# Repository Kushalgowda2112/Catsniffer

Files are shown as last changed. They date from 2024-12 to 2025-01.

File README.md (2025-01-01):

# **CatSniffer**

## Overview

CatSniffer 😼 is a multiprotocol, multiband device designed for sniffing, communicating, and attacking IoT (Internet of Things) devices. Shaped as a highly portable USB stick, it integrates powerful chips like **TI CC1352**, **Semtech SX1262**, and either the **RP2040** (for V3 and newer) or **Microchip SAMD21E17** (for V2 and earlier).

This device serves as a comprehensive tool for IoT security researchers, developers, and enthusiasts. CatSniffer is compatible with a wide range of software, including:

- SmartRF Packet Sniffer
- Sniffle
- zigbee2mqtt
- Z-Stack-firmware
- Ubiqua Protocol Analyzer
- Custom applications tailored to your specific needs

---

## Supported Technologies

CatSniffer can operate across multiple protocols:
- **LoRa**
- **Sub-1 GHz**
- **2.4 GHz**

Inspired by the work of Michael Ossmann and tools like the YardStick, GreatFET, HackRF, and Ubertooth, CatSniffer pays homage to the open-source hardware community.

---

## Versions

CatSniffer has evolved through several iterations, each improving on the previous:
- **CatSniffer v1.2**
- **CatSniffer v1.3**
- **CatSniffer v2.0**
- **CatSniffer v2.1**
- **CatSniffer v3.1**

All versions are supported, but newer versions include additional features and enhancements. Firmware for each version is tracked separately within the repository for clarity and ease of access.

---

## Protocols Supported

CatSniffer is compatible with the following protocols:
- **Thread**
- **Zigbee**
- **Bluetooth 5 Low Energy (BLE)**
- **IEEE 802.15.4g**
- **6LoWPAN**
- **LoRa/LoRaWAN**
- **Wi-SUN**
- **Amazon Sidewalk**
- **mioty®**

---

## Features

- **Multiprotocol and Multi-Band:** Operates across LoRa, Sub-1 GHz, and 2.4 GHz frequencies.
- **Auto Programming:** Integrated bootloader from TI CC; no external programmer needed.
- **User-Friendly Design:** Includes LEDs for status, reset buttons, and a general-purpose button.
- **Customizable:** SMA port for antenna selection and support for custom firmware or software development.
- **Cross-Platform Compatibility:** Works with Windows and Linux.

---

## Compatible Software

CatSniffer works with multiple software tools for sniffing and debugging:
- **Smart RF Packet Sniffer 2**
- **Wireshark**
- **Sniffle**
- **zigbee2mqtt**
- **Z-Stack-firmware**
- **pycatsniffer** (Beta)
- **Ubiqua Protocol Analyzer**

---

## Pre-requisites for Building Firmware

- **IDE:** Arduino IDE for RP2040 or SAMD21E17
- **Compiler:** Code Composer Studio (tested with CCS 10.2)
- **SDK:** SimpleLink CC13x2 and CC26x2 SDK
- **Programming Language:** Python 3

---

## License

- **Firmware License:** Released under a **GNU AGPL v3.0** license. See the `LICENSE` file for more information.
- **Hardware License:** Released under a **CERN Open Hardware Licence v1.2**. See the `LICENSE_HARDWARE` file for more details.

---

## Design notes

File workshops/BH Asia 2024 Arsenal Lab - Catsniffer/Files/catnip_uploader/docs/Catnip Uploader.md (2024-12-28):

This script works to upload firmware from the releases page to the CatSniffer Board V3.x. 
>[!IMPORTANT]
>The current version of the **Catnip** requires the lasted version of the [**SerialPassthroughwithboot**](https://github.com/ElectronicCats/CatSniffer-Firmware/releases/download/board-v3.x-v1.1.0/SerialPassthroughwithboot_RP2040_v1.1.uf2)
## Getting Starter
The struct files from the repo is:
``` bash
.catnip-uploader:
├── catnip_uploader.py
├── cc2538.py
├── releases.json
└── requirements.txt
```

To initialize first we need to install de dependencies packets from the *requirements.txt*. 

>[!NOTE]
>We recommend use virtual environment to avoid dependencies errors.

To install de requirements run the next command:  `pip install -r requirements.txt`
Requirements packets:
- `typer==0.9.0`
- `pyserial==3.5`
- `requests==2.31.0`
- `intelhex==2.3.0`
- `python-magic==0.4.27`

>[!IMPORTANT]
>To install **python-magic** may have additional dependencies depending on your OS, [read more](https://github.com/ahupp/python-magic#dependencies): 

### Available commands
Commands

#### Releases
Release commands
Show the current releases loaded from the board version 3
##### Usage
To show the current releases run the next command:
```bash
$> python3 catnip_uploader.py releases
Releases available:
0: airtag_scanner_CC1352P_7.hex
1: airtag_spoofer_CC1352P_7.hex
2: sniffer_fw_CC1352P_7.hex
3: sniffle_CC1352P_7.hex
```
#### Load
load_commands Load commands
Load  the selected firmware to the board, this command have two options.
- **Firmware**: This options is a integer value from the index of the available firmware releases
- **Comport**: The Path to the board serial com
##### Usage
>[!NOTE]
>First you need to know the index of the firmware you want to upload, exec the **releases** command if you don't know what index you need.

```bash
$> python3 catnip_uploader.py load 0 /dev/cu.usbmodem101
Uploading airtag_scanner_CC1352P_7.hex to /dev/cu.usbmodem1101
Downloading airtag_scanner_CC1352P_7.hex
Uploading airtag_scanner_CC1352P_7.hex to /dev/cu.usbmodem1101
Opening port /dev/cu.usbmodem1101, baud 500000
Reading data from firmware.hex
Firmware file: Intel Hex
Connecting to target...
CC1350 PG2.0 (7x7mm): 704KB Flash, 20KB SRAM, CCFG.BL_CONFIG at 0x000AFFD8
Primary IEEE Address: 00:12:4B:00:2A:79:C0:96
    Performing mass erase
Erasing all main bank flash sectors
    Erase done
Writing 720896 bytes starting at address 0x00000000
Write 208 bytes at 0x000AFF300
    Write done                                
Verifying by comparing CRC32 calculations.
    Verified (match: 0x99d1c8f1)
Done uploading airtag_scanner_CC1352P_7.hex to /dev/cu.usbmodem1101 
```

After finished you can use the CatSniffer with the selected firmware.

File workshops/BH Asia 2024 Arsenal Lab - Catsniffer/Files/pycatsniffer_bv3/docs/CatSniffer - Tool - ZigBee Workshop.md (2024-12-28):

This document show how to get key from a ZigBee communication and decrypt to know the value, for the POC was used a *Mi Smart Sensor Set* of Xiaomi.

# Setting up
Firs we need to clone the [CatSniffer tools set](https://github.com/ElectronicCats/CatSniffer-Tools), this repo contains the follow tools:
```bash
.catsniffer-tools
├── catnip_uploader
├── cc2538-bsl
└── pycatsniffer_bv3
```

Create a virtual environment to install the requirements, for more information about the **cc2538-bsl** read the [documentation repo](https://github.com/ElectronicCats/CatSniffer-Tools/tree/main/cc2538-bsl).

## Catnip Uploader

>[!IMPORTANT]
> To load the firmware in this way you need the lasted version of the **SerialPassthroughwithboot**.

With this tools we can upload the lasted firmware to the board v 3.x, to run first install the *requirements.txt*, with the following command: `pip install -r requirements.txt`.
Once the requirements are successfully installed we can upload the firmware:
- Run the *releases* command to know what releases are available:
	- `python3 catnip_uploader.py releases`
- Find the index of the *sniffer_fw_CC1352P_7.hex* and run the next command with the path of the port assigned to the board:
	- `python3 catnip_uploader.py load 0 <PORTCOM>`

For more information about the **Catnip Uploader** read the [repo](https://github.com/ElectronicCats/CatSniffer-Tools/blob/main/catnip_uploader/docs/Catnip%20Uploader.md).

> [!NOTE]
> if you have oldest version or you are not sure about what version of the **SerialPassthroughwithboot** you have, read the [**CC2538-bsl**](https://github.com/ElectronicCats/CatSniffer-Tools/tree/main/cc2538-bsl) to know how to upload the firmware with oldest version.
## PyCatsniffer
With the current virtual environment install the *requirements.txt* with the following command: `pip install -r requirements.txt`
Once the requirements are successfully installed we can continue installing the *dissectors*.
### Set the Dissector
We need to copy the three .lua files dissector to be able to read the information.
```bash
.dissectors:
├── catsniffer-blepi.lua
├── catsniffer-register.lua
└── catsniffer-rpi.lua
```

To copy the dissectors content we need to:
- Open Wireshark
- `Wireshark > About > Folders`
- Double click on the `Personal Lua Plugins` path (this create the folder path)
- Copy the content inside the *dissectors folder* into the **Personal Lua Plugins** folder
- Restart Wireshark

### Configure the DLT 147 value
To use wireshark and show the information we need to configure the USER DLT value to redirect the sniffer packet to the dissectors files.
- Open Wireshark
- `Preferences > Protocols > DLT_USER`
- Click on the `Edit...` button
- Create new entry
- The entry value are defined as:
	- DLT: User 0 (DLT=147)
	- Payload dissector: catsniffer_rpi
	- Header size: 0
- Click in *Ok* button
- Click in *Ok* button

if you have doubts with the installation read the [repo](https://github.com/ElectronicCats/CatSniffer-Tools/blob/main/catnip_uploader/docs/Catnip%20Uploader.md).

# Sniffing
To know how the *PyCatsniffer* works, please read the [repo](https://github.com/ElectronicCats/CatSniffer-Tools/blob/main/catnip_uploader/docs/Catnip%20Uploader.md).

We run the next command to sniff the IEEE 802.15.4 protocol, channel 11 and create a wireshark pipeline:
`python3 pycatsniffer.py /dev/cu.usbmodem101 -phy 1 -ch 11 -ff -ws -v`

Once the wireshark is open we can sniff the packets.
## Setting Up ZigBee Key
The **Default Trust Center Link Key** (Link Key) is a 16-bytes key.
The following key is defined by the ZigBee Alliance: `5A:69:67:42:65:65:41:6C:6C:69:61:6E:63:65:30:39`
To decrypt the packet information we need to add the key to the protocols section:
- `Wireshark > Preferences > Protocols > ZigBee`
- Edit the *preconfigure keys*
- Add new entry
- Copy the Key value
- Add
- Close the protocols window

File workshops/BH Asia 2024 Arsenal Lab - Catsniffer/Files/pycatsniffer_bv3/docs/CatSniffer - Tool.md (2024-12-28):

# PyCatsniffer tool

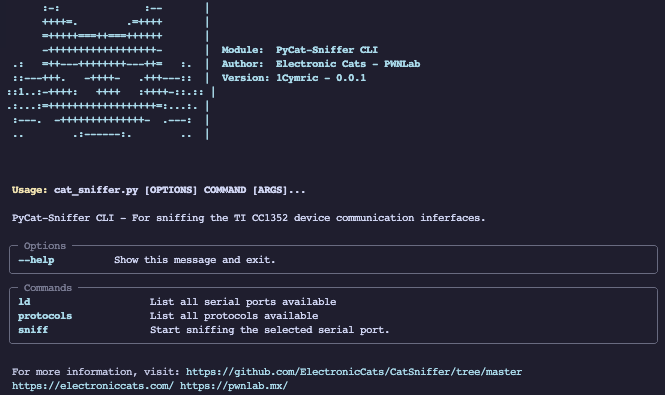
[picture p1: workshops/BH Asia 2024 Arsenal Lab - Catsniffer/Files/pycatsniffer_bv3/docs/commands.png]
commands

This tools is Command Line Interface (CLI) to communicate with the [**Sniffer_fw_CC1352P_7 firmware**](https://github.com/ElectronicCats/CatSniffer-Firmware/releases/) that you can upload with out catnip tool.

# Features
- This tool actually supports the next protocols:
	- Bluetooth Low Energy (BLE)
	- IEEE 802.15.4
	- ZigBee
- Multi platform support
- Direct wireshark communication with PIPE's
- Dump the received packets in:
	- Pcap Format
	- Hex Format

# Getting Starter
## Requirements
To install the requirements we need first [**Python 3**](https://www.python.org) installed and the environment variable to call python.
To initialize first we need to install de dependencies packets from the *requirements.txt*.

>[!NOTE]
>We recommend use virtual environment to avoid dependencies errors.

To install de requirements run the next command:  `pip install -r requirements.txt`
If all the requirements are satisfactory installed we can proceed to running the script.

## Setting up the Environment

### Wireshark
#### Set the Dissector
We need to copy the three .lua files dissector to be able to read the information.
```bash
.dissectors:
├── catsniffer-blepi.lua
├── catsniffer-register.lua
└── catsniffer-rpi.lua
```

To copy the dissectors content we need to:
- Open Wireshark
- `Wireshark > About > Folders`
- Double click on the `Personal Lua Plugins` path (this create the folder path)
- Copy the content inside the *dissectors folder* into the **Personal Lua Plugins** folder
- Restart Wireshark

#### Configure the DLT 147 value
To use wireshark and show the information we need to configure the USER DLT value to redirect the sniffer packet to the dissectors files.
- Open Wireshark
- `Preferences > Protocols > DLT_USER`
- Click on the `Edit...` button
- Create new entry
- The entry value are defined as:
	- DLT: User 0 (DLT=147)
	- Payload dissector: catsniffer_rpi
	- Header size: 0
- Click in *Ok* button
- Click in *Ok* button
## Available Commands
### List Devices - ld

```bash
$ python cat_sniffer.py ld
```

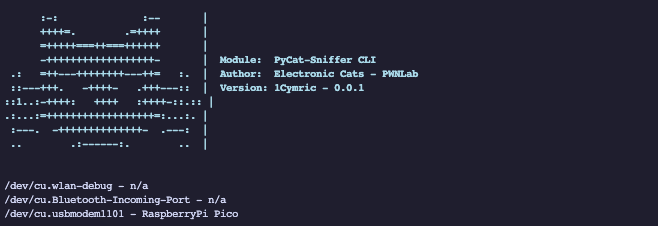
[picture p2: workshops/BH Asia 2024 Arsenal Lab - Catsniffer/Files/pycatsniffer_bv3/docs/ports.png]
List devices

This commands show the available com ports, running this command we can view what port is available and if our CatSniffer is connected.

### Protocols - protocols
```bash
$ python cat_sniffer.py protocols
```
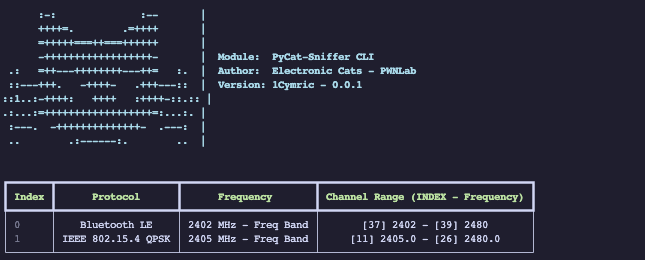
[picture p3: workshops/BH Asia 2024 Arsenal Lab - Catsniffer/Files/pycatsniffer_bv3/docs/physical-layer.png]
physical Layer protocols

This command show the available protocols and description about the supported channels.

The command show a table with the information about the protocol support.
- **Index**: The index value to used when a [sniff](#) command is called.
- **Protocol**: Protocol name
- **Frequency**: The base frequency of the protocol
- **Channel Range**: Show the relation of the channel and the frequency, the index value is used in the *sniff* command to select the channel to sniff.

>[!NOTE]
>The Channel Range is showed in the min value and max value of the channel range available in the protocol.

### Sniffer - sniff

```bash
$ python cat_sniffer.py sniff --help
```

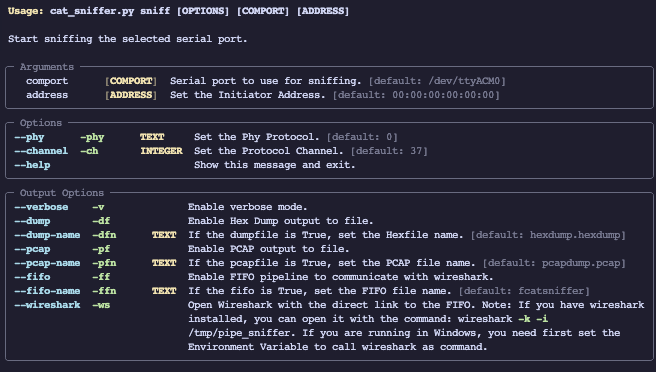
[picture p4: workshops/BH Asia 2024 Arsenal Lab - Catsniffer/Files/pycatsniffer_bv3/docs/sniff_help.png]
sniff Sniff Help


This commands initialize the sniff communication with the board, to start the sniffing the command requires some initial configuration.

#### Arguments:
- **comport**: This value is the path to the board serial com
- **address (experimental)**: This value is the MAC address of the device to follow the connection

#### Options
- **phy**: This value set the phy value, as refers in the [protocols section] correspond to the index value.
- **channel**: This is the value from the channel to sniff, this index values are showed in the protocols section.

When a different *phy* is selected, we need to specify the channel to sniffing.

#### Output Options
- **verbose**: Show the sniffed packets in the console.
- **dump**: Is a flag value, if we write this will generate a dump hex file
- **dump-name**: Is the flag value, if we write this with a value change the default dump name.
- **pcap**: Is a flag value, if we write this will generate a dump pcap file
- **pcap-name**: Is the flag value, if we write this with a value change the default dump name.
- **fifo**: This flags set a pipe line to communicate with wireshark
- **fifo-name**: Set the name of the pipe
- **wireshark**: This open a wireshark in the same thread of the script and open automatically the fifo. (Require the -ff option to open)

>[!IMPORTANT]
>If your are in windows to call Wireshark from the terminal you need to set the installation path to the Environmental Variables

### Examples calls

$SERIAL_PORT will be depending on your OS please check your serial port name by: 

```bash
$ python cat_sniffer.py ld
```
List devices

Default sniffing
- Protocol: BLE
- Channel: 37
- Verbose
```bash
$ python3 cat_sniffer.py sniff $SERIAL_PORT -v
```

Dump a pcap file with different BLE channel
- Protocol: BLE
- Channel: 39
- Dump File
```bash
$ python3 cat_sniffer.py sniff $SERIAL_PORT -ch 39 -df
```

Default sniffing
- Protocol: BLE
- Channel: 37
- Wireshark
```bash
$ python3 cat_sniffer.py sniff $SERIAL_PORT -phy 0 -ch 39 -ff -ws 
```

Dump a pcap file, hex file with custom name and IEEE 802.15.4 protocol
```bash
$ python3 cat_sniffer.py sniff $SERIAL_PORT -phy 1 -ch 11 -pf -df -dfn test.pcap
```

Dump a pcap file, hex file, verbose mode and show the packets on wireshark
```bash
$ python3 cat_sniffer.py sniff $SERIAL_PORT -df -pf -ff -ws
```

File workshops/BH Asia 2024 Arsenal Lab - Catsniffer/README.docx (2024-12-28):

# Practical IoT Hacking: Introduction to Multi-Band Hacking with the CatSniffer

Delve into the fascinating world of IoT (Internet of Things) with the CatSniffer - a powerful, multi-protocol, multi-band, and open-source board crafted for exploring, interacting, and potentially compromising IoT devices. This workshop offers an immersive, hands-on experience, teaching you how to create chaos among IoT devices and challenge real-world devices like property trackers.

Our engaging demonstrations are merely the tip of the iceberg of what you can achieve with the CatSniffer. The tool's exceptional flexibility allows the use of different tools for your security auditing needs, and our unique firmware broadens your learning horizon and amplifies the fun factor, irrespective of whether you're a novice or a seasoned expert in the field.

We invite you to join us on this journey of discovery, where we will harness the boundless capabilities of CatSniffer, fine-tuning your skills and transforming you into a maestro of IoT security auditing.

## Instructors

Paulino Calderon (@calderpwn) / https://calderonpale.com / https://pwnlab.mx / https://websec.mx / https://www.websec.ca

paulino@pwnlab.mx

Eduardo Contreras (@foreverwero) / https://electroniccats.com

e@electroniccats.com

## How to start

The first step is download our CatSniffer Tools repo, this contains all the tools to start the process.

Once you cloned the repo you can follow our Unleashing the Power of Catsniffer: Dive Deeper with Catnip (https://www.hackster.io/electronic-cats/unleashing-the-power-of-catsniffer-dive-deeper-with-catnip-82e1e4) tutorial posted in hackster.io to know how to use the Catnip tool to upload the firmware to the CatSniffer board.

## Additional References

- Link to this workshop: https://drive.google.com/drive/folders/1jL8F2wyyk_IrzVMoqUrraBWmWxnT-Cso
- Workshop booklet:

N/A

- Catsniffer on Github:

https://github.com/ElectronicCats/CatSniffer

- Catsniffer Wiki:

https://github.com/ElectronicCats/CatSniffer/wiki/

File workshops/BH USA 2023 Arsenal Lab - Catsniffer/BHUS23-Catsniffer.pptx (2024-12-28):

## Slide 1

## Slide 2

Practical IoT Hacking: Introduction to Multi-Band Hacking with the CatSniffer

Eduardo Wero (@foreverwero) / Paulino Calderon (@calderpwn)

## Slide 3

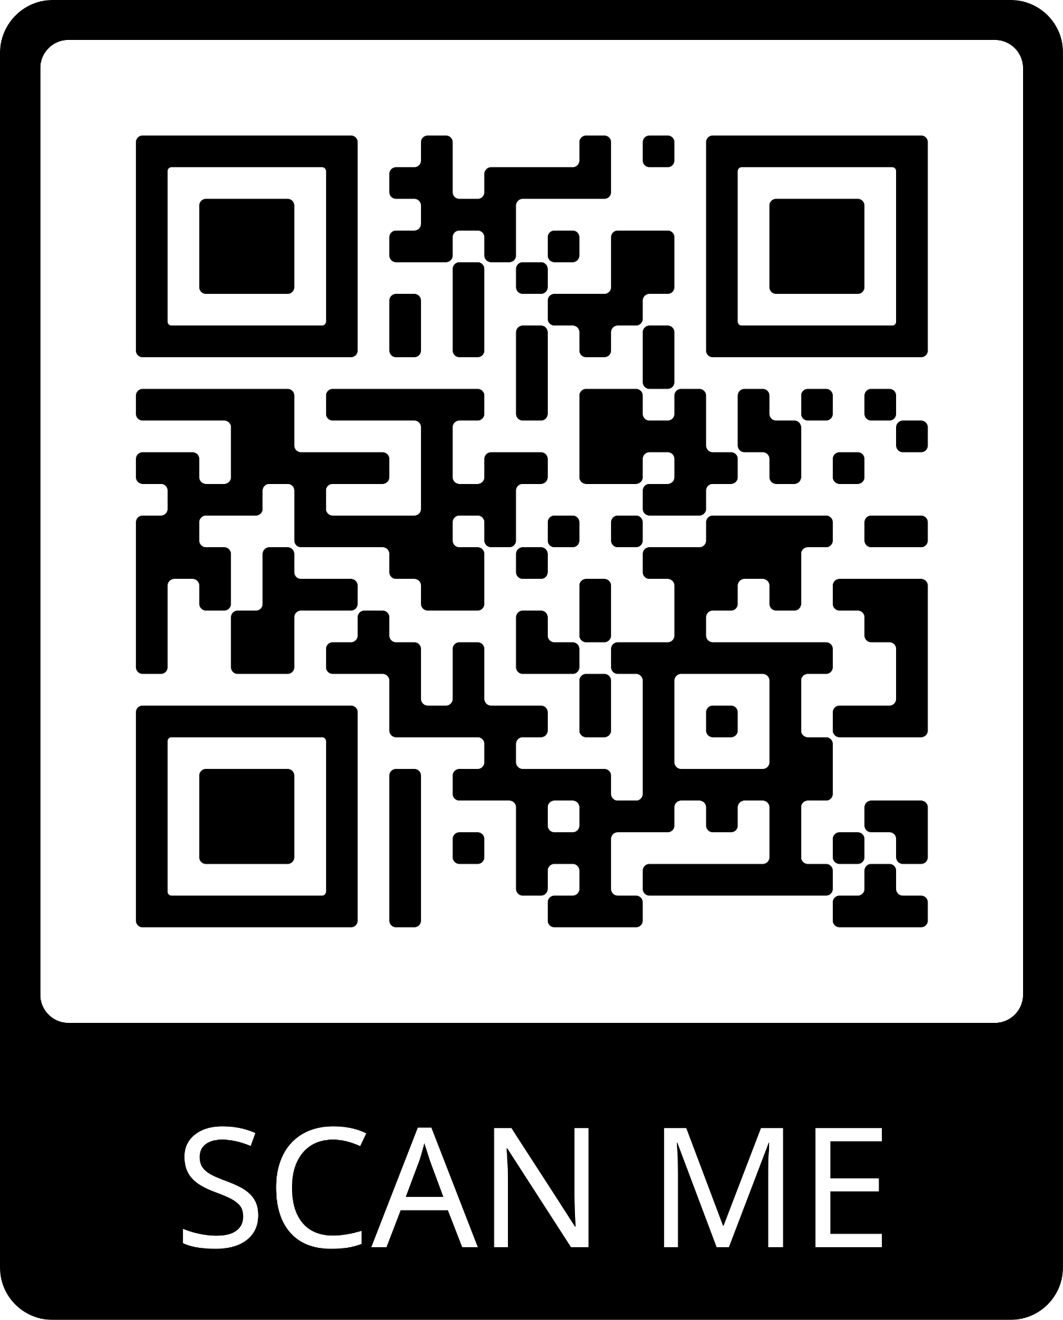
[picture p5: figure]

Workshop resources:

https://bit.ly/3Dsyqol

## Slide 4

CatSniffer

CatSniffer (😼) is an innovative, multi-protocol, multi-band open source circuit board made for sniffing, communicating, and attacking IoT (Internet of Things) devices. It was designed as a highly portable USB stick that integrates TI CC1352, Semtech SX1262, and Microchip SAMD21E17 (V1.x and V2.x)/RP2040 (V3.x).

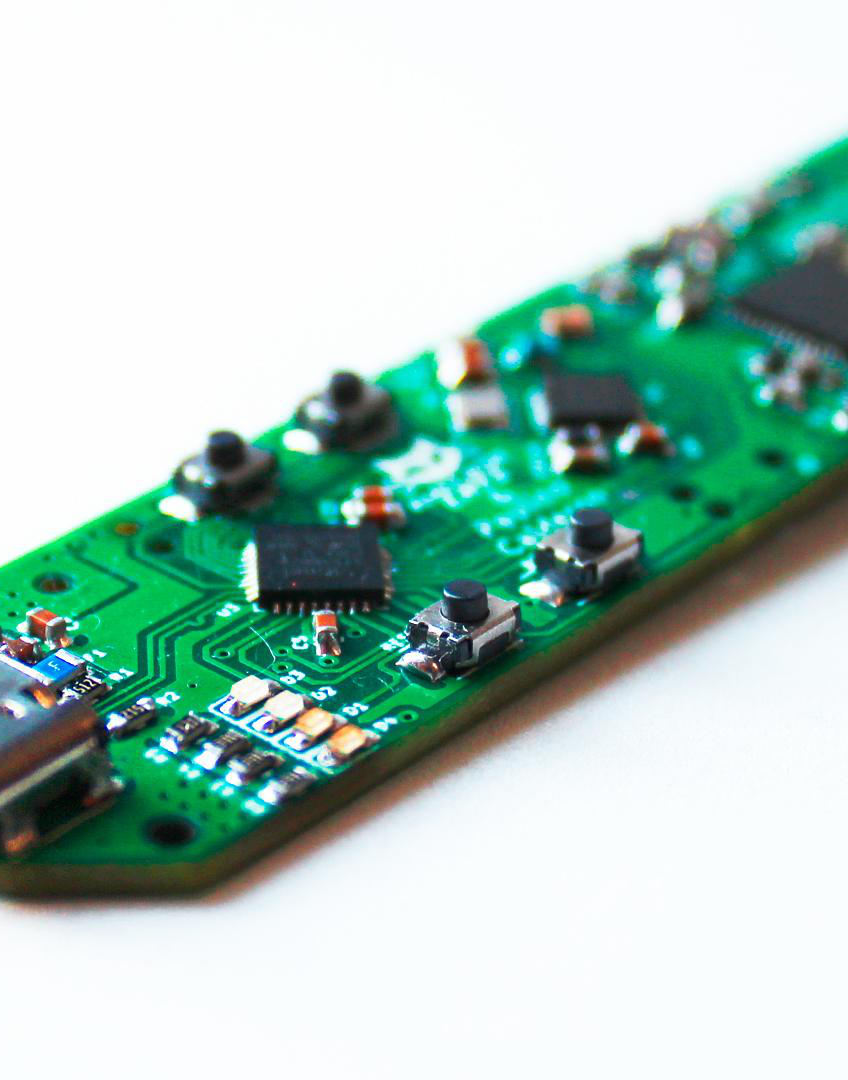
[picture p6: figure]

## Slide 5

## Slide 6

Supported software

This board is a Swiss army knife for IoT security researchers, developers, and enthusiasts. It's highly versatile, compatible with a wide array of software, including:
- Packet Sniffers (*)
- Security auditing tools
- Custom firmware developed by ElectronicCats/PWNLab
(*) It works in Windows with the latest Wireshark!

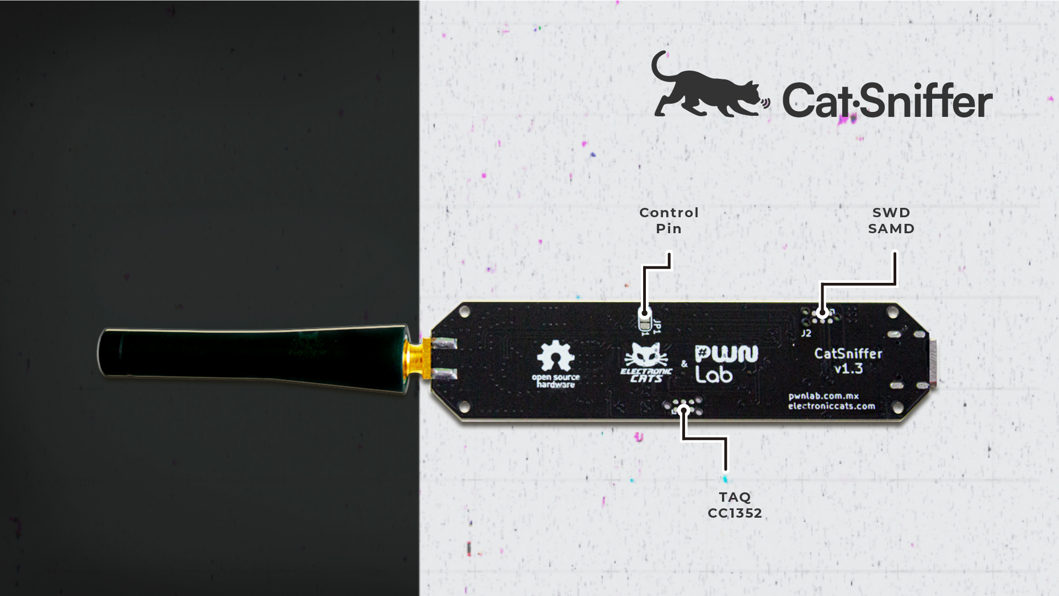
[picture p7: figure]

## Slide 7

Protocols

- Thread
- Zigbee
- Bluetooth 5 Low Energy (BLE)
- IEEE 802.15.4g
- 6LoWPAN (IPv6 over Low power Wireless Personal Area Networks)
- Sub 1Ghz and patented systems
- LoRa/LoRaWAN
Antenna support: 868/915 MHz up to 14 dBm, 2.4 GHz up to 20 dBm

1.x/2.x

- RP2040 microcontroller
- +Wi-SUN
- +Amazon Sidewalk
- +mioty®
Antena support: 433 MHz up to 13 dBm, 2.4 GHz up to 10 dBm

3.x

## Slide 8

SPI

Serial

SX1262

RF Switch

USB

RP2040

CC1352P7

JTAG

GPIOs

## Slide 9

Workshop prerequisites

To challenge yourself and follow along, you will need the following software (*):
- Workshop booklet
https://bit.ly/44yWQsj
- Code Composer Studio from https://www.ti.com/tool/CCSTUDIO
- Code sources from https://github.com/ElectronicCats/CatSniffer/
- Python3 (pyserial and other modules might be needed)
(*) It should be pre-installed in the Kali workstations but USBs with all the files should be available to copy the files to your machines!

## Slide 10

Flashing firmware from Linux

To program your Catsniffer with one of the firmwares available:
1. Locate the desired firmware. You will usually find official firmwares in .hex format.
https://github.com/ElectronicCats/CatSniffer/tree/master/firmware
1. Put the CatSniffer in upload mode for the CC1352P7, press reset for the RP2040 and the boot for the CC1352, then release the reset button and second the boot button, you shall see an animation on the LEDs in the CatSniffer, you are ready to upload the desire firmware to the CC1352.
2. Locate the utility cc2538-bsl.py found in the Code folder.
3. Install the requirements for cc2538-bsl.py by issuing the following commands:
$python3 -m pip install pyserial
$python3 -m pip install intelhex
1. Reset the RP2040 once you have flashed the CC1352P
2. If you would like to read serial information from a terminal, put back the CatSniffer in serial passthrough mode with the correct speed using Arduino IDE. (Optional)

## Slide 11

Practical examples

Follow along with booklet

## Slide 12

Hands on Lab #1: Sniffing BLE

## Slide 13

Learning objectives

1. Flash firmware for sniffing Bluetooth Low Energy connections
2. Basic usage of tools for analyzing BLE traffic
3. Packet structure of different types of BLE packets

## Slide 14

Hands on Lab #2: Detecting personal trackers

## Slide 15

Learning objectives

1. Learn about the technologies used in personal trackers
2. Learn how to detect personal trackers
3. Write custom firmware to detect personal trackers

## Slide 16

Hands on Lab #3: Spoofing personal trackers

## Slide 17

Learning objectives

1. Learn how to spoof personal trackers
2. Learn to craft custom BLE packets
3. Write firmware to communicate with devices over BLE

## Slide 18

Questions?

Eduardo Contreras (e@electroniccats.com)
Paulino Calderon (paulino@pwnlab.mx)
Catsniffer on Github
https://github.com/ElectronicCats/CatSniffer
Download this workshop: https://bit.ly/3Dsyqol

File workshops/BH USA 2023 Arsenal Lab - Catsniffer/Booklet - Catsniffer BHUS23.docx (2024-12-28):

# Practical IoT Hacking: Introduction to Multi-Band Hacking with the CatSniffer

# Introduction

CatSniffer (😼) is an innovative, multi-protocol, multi-band circuit board for sniffing, communicating, and attacking IoT (Internet of Things) devices. It was designed as a highly portable USB stick that integrates TI CC1352, Semtech SX1262, and Microchip SAMD21E17 (V1.x and V2.x)/RP2040 (V3.x). This board is a Swiss army knife for IoT security researchers, developers, and enthusiasts.

It's highly versatile and compatible with a wide array of software, including:

- Packet Sniffers
- Security auditing tools
- Custom firmware developed by ElectronicCats/PWNLab

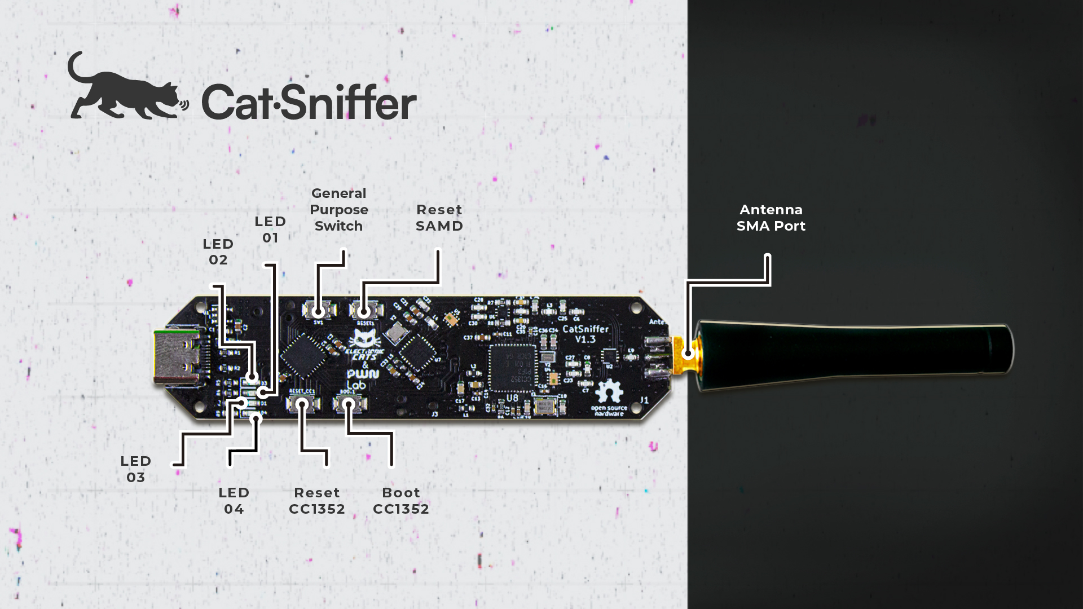
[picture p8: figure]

# Prerequisites for this lab

- Code Composer Studio from https://www.ti.com/tool/CCSTUDIO
- Code sources from https://github.com/ElectronicCats/CatSniffer/
- Code sources from https://github.com/nccgroup/Sniffle
- Code sources from this lab https://drive.google.com/drive/u/0/folders/1gAhvl0LL4fa0lKgpV9UGBT3YMNm0QPBm
- Intro slides are available here, although everything you need is in this booklet: https://docs.google.com/presentation/d/1xlIV50EbMossOGwUigmQGIvOejEj4H3sAvrZ4WhhDQM/
- Or just download everything from here:

<ADD LINK HERE>

# Flashing firmware from Linux/Mac

To program your CatSniffer with one of the many firmware files available:

1. Locate the desired firmware. You will usually find the firmware in .hex format.

https://github.com/ElectronicCats/CatSniffer/tree/master/firmware

2. Put the CatSniffer in upload mode for the CC1352P7 (Catsniffer v3.x) by holding both the reset button for the RP2040 and the boot for the CC1352 (See image below), then releasing the reset button first and then the boot button. You should see an animation on the LEDs in the CatSniffer.

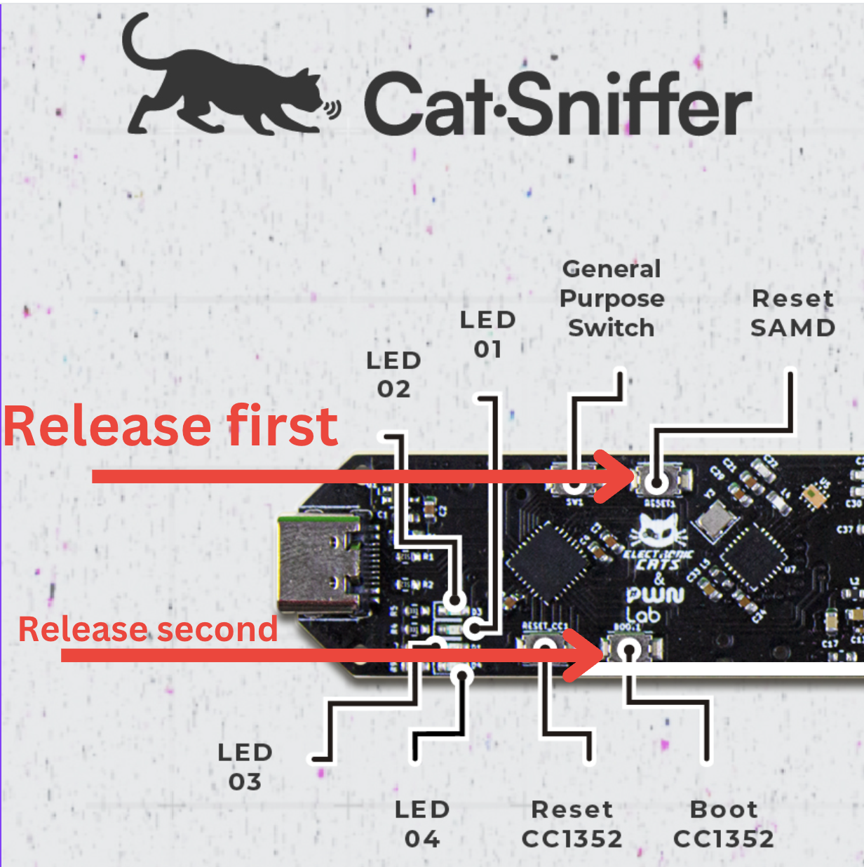
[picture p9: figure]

3. Locate the utility cc2538-bsl.py in the folder /Code/ (Or /tools/cc2538-bsl/ if you are working with the latest version of the Catsniffer’s GitHub repository).
4. Install the requirements for cc2538-bsl.py by issuing the following commands:

$python3 -m pip install pyserial

$python3 -m pip install intelhex

5. Reset the RP2040 (Reset SAMD in v2.x) once you have flashed the CC1352P chip.
6. If you want to read serial information from a terminal, put the CatSniffer back in serial passthrough mode with the correct speed using Arduino IDE. (Optional)
7. Run the command

python3 cc2538-bsl.py -e -w -v -p <SERIAL PORT> <HEX FILE>

# Putting the CatSniffer in serial passthrough mode

1. Connect the Catsniffer to your computer
2. Press the button: Reset SAMD
3. You should see the LED 03 blink every ~1 sec.

# Determine the serial port used by the Catsniffer

Linux Instructions:

1. Make sure the CatSniffer is disconnected from your computer
2. List the serial devices available before connecting the Catsniffer:

% ls /dev/cu.usb*

3. Connect your CatSniffer via USB and list the serial devices available again. The new device in the list should be your Catsniffer:

% ls /dev/cu.usb*

4. In this case, the serial port in your computer is /dev/cu.usbmodem2101. Note that this value may change upon reconnections, and it is affected by the number of serial devices available in your computer.

Mac Instructions:

1. Make sure the CatSniffer is disconnected from your computer
2. List the serial devices available before connecting the Catsniffer:

% ls /dev/cu.usb*

3. Connect your CatSniffer via USB and list the serial devices available again. The new device in the list should be your Catsniffer:

% ls /dev/cu.usb*

4. In this case, the serial port in your computer is /dev/cu.usbmodem2101. Note that this value may change upon reconnections and is affected by the number of serial devices available on your computer.

# Putting the Catsniffer in upload mode

1. Connect the Catsniffer to your computer
2. Press and hold the buttons Reset SAMD and Boot CC1352
3. Release the button Reset SAMD while holding the button Boot CC1352
4. Release the button Boot CC1352
5. You should see an LED cascading animation to indicate the CatSniffer is in upload mode.

# Hands-on Lab #1: Sniffing BLE Beacons

## Objectives

- Flash firmware for sniffing Bluetooth Low Energy connections
- Basic usage of tools for analyzing BLE traffic
- Packet structure of different types of BLE packets

## Challenge

Flash firmware for sniffing traffic and capturing BLE traffic to analyze and learn more about the different types of advertisement packets in Bluetooth Low Energy devices. Attempt to identify the beacons emitted by the personal trackers around the lab.

## Walk-Through

1. Flash the firmware “Sniffle.hex” into the Cat Sniffer::

python3 cc2538-bsl.py -e -w -v -p <SERIAL PORT> Sniffle.hex

2. Run the Python script called sniff_receiver.py with the specific serial port number

./sniff_receiver.py -s <SERIAL PORT>

You should see BLE data on the terminal!

3. To configure Wireshark to read the traffic, we need to copy the Sniffle scripts into your personal EXTCAP folder:
  a. Find the location of your Personal Extcap folder in the Folders tab in the 'About Wireshark' dialog (Unix: Help > About Wireshark > Folders > Personal Extcap path | Mac: Wireshark > About Wireshark > Folders > ).
    i. On Unix systems, this folder is typically located at ~/.config/wireshark/extcap.
    ii. On Mac systems, this folder is located at

/Users/<user>/.config/wireshark/extcap

4. Copy the following files from the folder python_cli from the sniffle project directory into your Personal Extcap folder:
1. pcap.py
2. packet_decoder.py
3. sniffle_hw.py
4. sniffle_extcap.py
5. sniffle_extcap.bat (Windows only)
5. We need to modify the Python script “sniffle_extcap.py” as an executable. In Unix/Mac, use the following command:

chmod +x ~/.config/wireshark/extcap/sniffle_extcap.py

6. For Mac users only, you also need to make sure pyserial is installed in the python version used by Xcode:

cd /Applications/Xcode.app/Contents/Developer/Library/Frameworks/Python3.framework/Versions/Current/Resources/Python.app/Contents/MacOS

./Python -m ensurepip --default-pip

./Python -m pip install --user pyserial

7. Open Wireshark, and you should see a sniffle BLE interface listed now.
8. Ensure the correct serial port is configured in the interface before starting your capture. Reviewing some of the initial configuration options now.
9. Now, we will add a filter to see the BLE packets from a specific manufacturer.

btcommon.eir_ad.entry.company_id == 0x004c

10. Search for the specific packet that can match the next payload

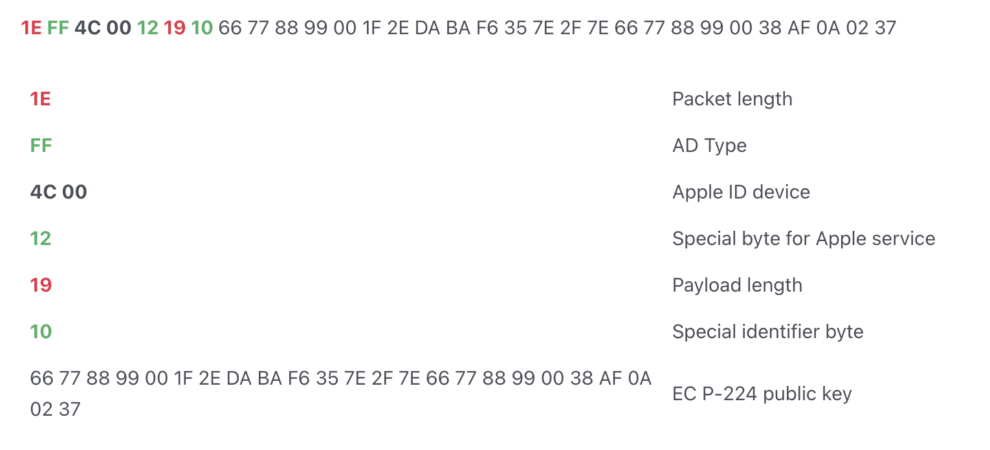
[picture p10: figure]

# Hands-on Lab #2: Detecting personal trackers

## Objectives

- Learn about the technologies used in personal trackers
- Learn how to detect personal trackers
- Write custom firmware to detect personal trackers

## Challenge

Finish the implementation of Lab2-Detecting-Trackers and detect all personal trackers around you with the Catsniffer.

## Walk-Through

1. Import the project Lab2-Detecting-Trackers into Code Composer Studio

(File -> Import).

If you see errors related to missing references, go to Project -> Properties -> Resource -> Linked Resources and update their location.

2. Once the project is loaded in Code Composer Studio, get familiar with the folder structure. Browse around the code base. The most important files for our purposes will be in the Application folder.
3. Go to the file Application/Lab2-Detecting-Trackers.c and locate the function AirtagScanner_processAppMsg. This function will contain the following nested-if statements to filter beacons that are registered and unregistered:

if(pAdvRpt->pData[0]==0x1E && pAdvRpt->pData[2]==0x4c && pAdvRpt->pData[3]==0x00) {

if (pAdvRpt->pData[4] == <Fill In> && pAdvRpt->pData[6] == <Fill In>){

Display_printf(dispHandle, 0, 0, "Airtag detected! -> %s Status: Registered and active", Util_convertBdAddr2Str(pAdvRpt->addr));

}

else if(pAdvRpt->pData[4] == <Fill In> && pAdvRpt->pData[6] == <Fill In>){

Display_printf(dispHandle, 0, 0, "Airtag detected! -> %s Status: Unregistered", Util_convertBdAddr2Str(pAdvRpt->addr));

}

}

4. Fill in the relevant bytes according to the analysis of the packet structure.
5. Build the project by clicking the Build icon on the toolbar
6. Locate the generated .hex file by right-clicking on the project name and then clicking on Show In Local Terminal -> System Explorer. This is the firmware file that you will be flashing to the Catsniffer, copy or move it to your desired location.
7. Flash the firmware into the Catsniffer as described in Flashing firmware from Linux.
8. Press the Reset button RP2040 (Catsniffer 3.x) or Reset SAMD (Catsniffer 2.x - 1.x)
9. We need to read the serial data to read the output generated by the Catsniffer. In Unix/Mac you may use the utility ‘screen’ installed by default in most systems:

$screen <device> <baud rate>

To use the serial port /dev/ttyACM0 and baud rate of 921600 (default baud rate), use the following command:

$screen /dev/ttyACM0 921600

10. You should see a message for every personal tracker detected!

# Hands-on Lab #3: Spoofing personal trackers

## Challenge

Finish the implementation Lab3-Spoofing-Trackers and spoof personal trackers with the Catsniffer

## Objectives

- Learn how to spoof personal trackers
- Learn to craft custom BLE packets
- Write firmware to communicate with devices over BLE

## Walk-Through

1. Import the project Lab2-Detecting-Trackers into Code Composer Studio (File -> Import).

If there are errors related to missing references, go to Project -> Properties -> Resource -> Linked Resources and update their location.

2. Once the project is loaded in Code Composer Studio, get familiar with the folder structure. Browse around the code base. The most important files for our purposes will be in the Application folder.
3. Go to the file Application/Lab3-Spoofing-Trackers.c and locate the function AirtagSpoofer_processGapMessage. Inside this function, you will find the C array airtag_adv_data. This is the structure containing the data used in the advertisement packet.
4. Update the content of this structure to match the content of an advertisement packet.
5. Build the project by clicking on the Build icon on the toolbar
6. Locate the generated .hex file by right-clicking on the project name and then clicking on Show In Local Terminal -> System Explorer. This is the firmware file you will be flashing to the Catsniffer, copy or move it to your desired location.
7. Flash the firmware into the Catsniffer as described in Flashing firmware from Linux.
8. Press the Reset button RP2040 (Catsniffer 3.x) or Reset SAMD (Catsniffer 2.x - 1.x)
9. We need to read the serial data to read the output generated by the Catsniffer. In Unix/Mac you may use the utility ‘screen’ installed by default in most systems:

$screen <device> <baud rate>

To use the serial port /dev/ttyACM0 and baud rate of 921600 (default baud rate), use the following command:

$screen /dev/ttyACM0 921600

10. Use the app Tracker Detect (Android/iOS). Every time you press the reset button, you should see a new personal tracker in the list!

Paulino Calderon - @calderpwn Eduardo Contreras - @foreverwero

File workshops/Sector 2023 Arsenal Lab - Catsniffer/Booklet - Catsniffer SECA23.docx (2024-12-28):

# Practical IoT Hacking: Introduction to Multi-Band Hacking with the CatSniffer

# Introduction

CatSniffer (😼) is an innovative, multi-protocol, multi-band circuit board for sniffing, communicating, and attacking IoT (Internet of Things) devices. It was designed as a highly portable USB stick that integrates TI CC1352, Semtech SX1262, and Microchip SAMD21E17 (V1.x and V2.x)/RP2040 (V3.x). This board is a Swiss army knife for IoT security researchers, developers, and enthusiasts.

It's highly versatile and compatible with a wide array of software, including:

- Packet Sniffers
- Security auditing tools
- Custom firmware developed by ElectronicCats/PWNLab

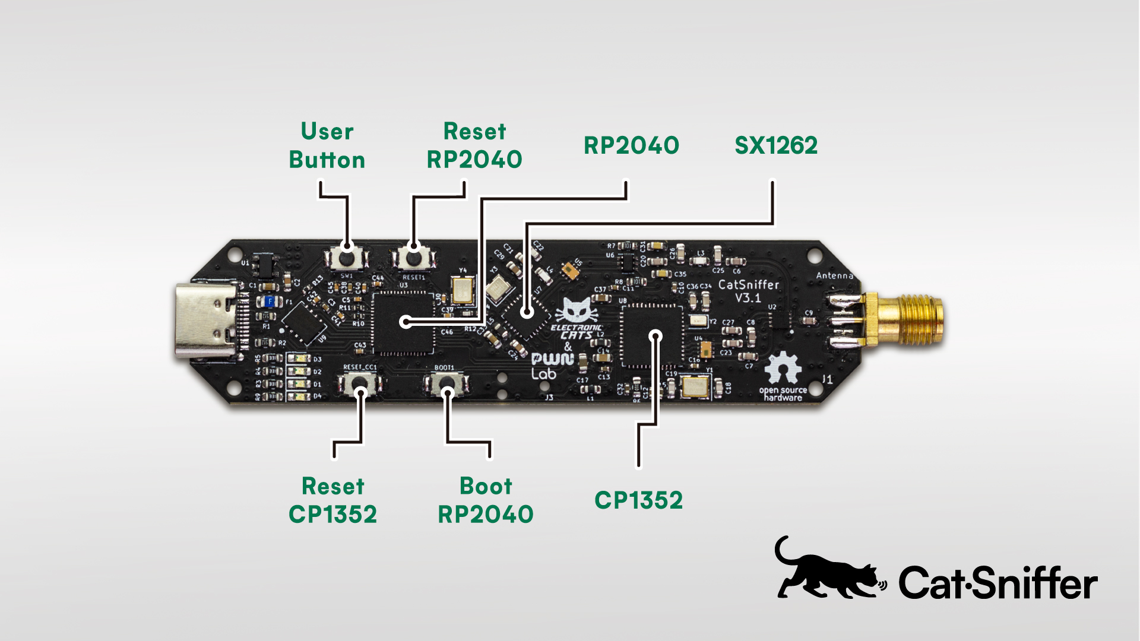
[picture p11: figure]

# Prerequisites for this lab

- Code Composer Studio from https://www.ti.com/tool/CCSTUDIO
- Code sources from https://github.com/ElectronicCats/CatSniffer/
- Code sources from https://github.com/nccgroup/Sniffle
- Code sources from this lab https://drive.google.com/drive/u/0/folders/1gAhvl0LL4fa0lKgpV9UGBT3YMNm0QPBm
- Intro slides are available here, although everything you need is in this booklet: https://docs.google.com/presentation/d/1xlIV50EbMossOGwUigmQGIvOejEj4H3sAvrZ4WhhDQM/
- Or just download everything from here:

<ADD LINK HERE>

# Flashing firmware from Linux/Mac/Windows

To program your CatSniffer with one of the many firmware files available:

1. Locate the desired firmware. You will usually find the firmware in .hex format.

https://github.com/ElectronicCats/CatSniffer/tree/master/firmware

2. Put the CatSniffer in upload mode for the CC1352P7 (Catsniffer v3.x) by holding both the reset button for the RP2040 and the boot for the CC1352 (See image below), then releasing the reset button first and then the boot button. You should see an animation on the LEDs in the CatSniffer.

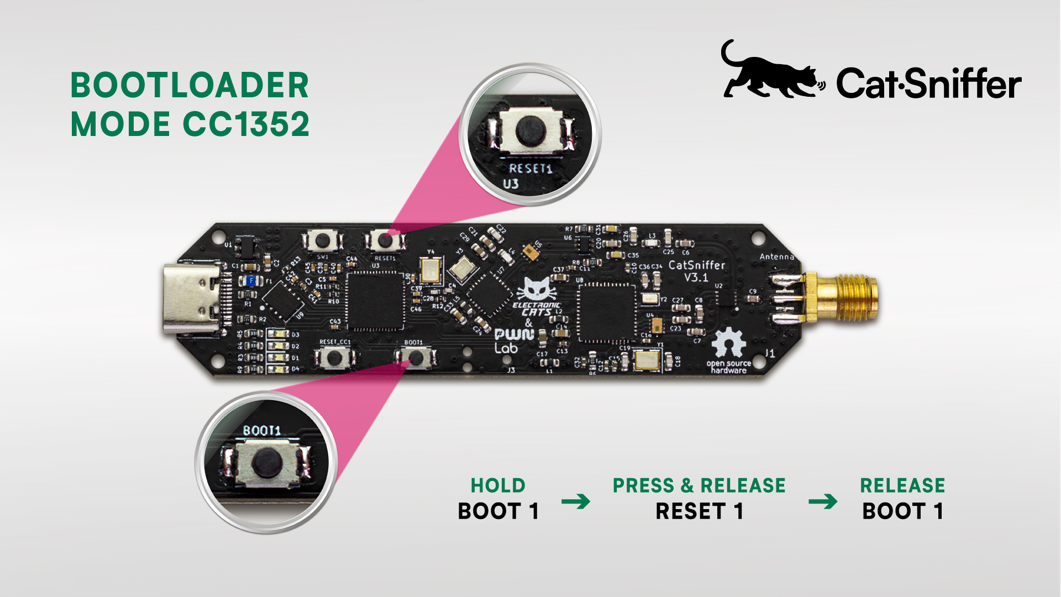
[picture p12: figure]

3. Locate the utility cc2538-bsl.py in the folder /Code/ (Or /tools/cc2538-bsl/ if you are working with the latest version of the Catsniffer’s GitHub repository).
4. Install the requirements for cc2538-bsl.py by issuing the following commands:

$python3 -m pip install pyserial

$python3 -m pip install intelhex

5. Reset the RP2040 (Reset SAMD in v2.x) once you have flashed the CC1352P chip.
6. If you want to read serial information from a terminal, put the CatSniffer back in serial passthrough mode with the correct speed using Arduino IDE. (Optional)
7. Run the command

python3 cc2538-bsl.py -e -w -v -p <SERIAL PORT> <HEX FILE>

# Putting the CatSniffer in serial passthrough mode

1. Connect the Catsniffer to your computer
2. Press the button: Reset SAMD
3. You should see the LED 03 blink every ~1 sec.

# Determine the serial port used by the Catsniffer

Linux Instructions:

1. Make sure the CatSniffer is disconnected from your computer
2. List the serial devices available before connecting the Catsniffer:

% ls /dev/cu.usb*

3. Connect your CatSniffer via USB and list the serial devices available again. The new device in the list should be your Catsniffer:

% ls /dev/cu.usb*

4. In this case, the serial port in your computer is /dev/cu.usbmodem2101. Note that this value may change upon reconnections, and it is affected by the number of serial devices available in your computer.

Mac Instructions:

1. Make sure the CatSniffer is disconnected from your computer
2. List the serial devices available before connecting the Catsniffer:

% ls /dev/cu.usb*

3. Connect your CatSniffer via USB and list the serial devices available again. The new device in the list should be your Catsniffer:

% ls /dev/cu.usb*

4. In this case, the serial port in your computer is /dev/cu.usbmodem2101. Note that this value may change upon reconnections and is affected by the number of serial devices available on your computer.

# Putting the Catsniffer in upload mode

1. Connect the Catsniffer to your computer
2. Press and hold the buttons Reset SAMD and Boot CC1352
3. Release the button Reset SAMD while holding the button Boot CC1352
4. Release the button Boot CC1352
5. You should see an LED cascading animation to indicate the CatSniffer is in upload mode.

# Hands-on Lab #1: Sniffing BLE Beacons

## Objectives

- Flash firmware for sniffing Bluetooth Low Energy connections
- Basic usage of tools for analyzing BLE traffic
- Packet structure of different types of BLE packets

## Challenge

Flash firmware for sniffing traffic and capturing BLE traffic to analyze and learn more about the different types of advertisement packets in Bluetooth Low Energy devices. Attempt to identify the beacons emitted by the personal trackers around the lab.

## Walk-Through

1. Flash the firmware “Sniffle.hex” into the Cat Sniffer::

python3 cc2538-bsl.py -e -w -v -p <SERIAL PORT> Sniffle.hex

2. Run the Python script called sniff_receiver.py with the specific serial port number

./sniff_receiver.py -s <SERIAL PORT>

You should see BLE data on the terminal!

3. To configure Wireshark to read the traffic, we need to copy the Sniffle scripts into your personal EXTCAP folder:
  a. Find the location of your Personal Extcap folder in the Folders tab in the 'About Wireshark' dialog (Unix: Help > About Wireshark > Folders > Personal Extcap path | Mac: Wireshark > About Wireshark > Folders > ).
    i. On Unix systems, this folder is typically located at ~/.config/wireshark/extcap.
    ii. On Mac systems, this folder is located at

/Users/<user>/.config/wireshark/extcap

4. Copy the following files from the folder python_cli from the sniffle project directory into your Personal Extcap folder:
1. pcap.py
2. packet_decoder.py
3. sniffle_hw.py
4. sniffle_extcap.py
5. sniffle_extcap.bat (Windows only)
5. We need to modify the Python script “sniffle_extcap.py” as an executable. In Unix/Mac, use the following command:

chmod +x ~/.config/wireshark/extcap/sniffle_extcap.py

6. For Mac users only, you also need to make sure pyserial is installed in the python version used by Xcode:

cd /Applications/Xcode.app/Contents/Developer/Library/Frameworks/Python3.framework/Versions/Current/Resources/Python.app/Contents/MacOS

./Python -m ensurepip --default-pip

./Python -m pip install --user pyserial

7. Open Wireshark, and you should see a sniffle BLE interface listed now.
8. Ensure the correct serial port is configured in the interface before starting your capture. Reviewing some of the initial configuration options now.
9. Now, we will add a filter to see the BLE packets from a specific manufacturer.

btcommon.eir_ad.entry.company_id == 0x004c

10. Search for the specific packet that can match the next payload


# Hands-on Lab #2: Detecting personal trackers

## Objectives

- Learn about the technologies used in personal trackers
- Learn how to detect personal trackers
- Write custom firmware to detect personal trackers

## Challenge

Finish the implementation of Lab2-Detecting-Trackers and detect all personal trackers around you with the Catsniffer.

## Walk-Through

1. Import the project Lab2-Detecting-Trackers into Code Composer Studio

(File -> Import).

If you see errors related to missing references, go to Project -> Properties -> Resource -> Linked Resources and update their location.

2. Once the project is loaded in Code Composer Studio, get familiar with the folder structure. Browse around the code base. The most important files for our purposes will be in the Application folder.
3. Go to the file Application/Lab2-Detecting-Trackers.c and locate the function AirtagScanner_processAppMsg. This function will contain the following nested-if statements to filter beacons that are registered and unregistered:

if(pAdvRpt->pData[0]==0x1E && pAdvRpt->pData[2]==0x4c && pAdvRpt->pData[3]==0x00) {

if (pAdvRpt->pData[4] == <Fill In> && pAdvRpt->pData[6] == <Fill In>){

Display_printf(dispHandle, 0, 0, "Airtag detected! -> %s Status: Registered and active", Util_convertBdAddr2Str(pAdvRpt->addr));

}

else if(pAdvRpt->pData[4] == <Fill In> && pAdvRpt->pData[6] == <Fill In>){

Display_printf(dispHandle, 0, 0, "Airtag detected! -> %s Status: Unregistered", Util_convertBdAddr2Str(pAdvRpt->addr));

}

}

4. Fill in the relevant bytes according to the analysis of the packet structure.
5. Build the project by clicking the Build icon on the toolbar
6. Locate the generated .hex file by right-clicking on the project name and then clicking on Show In Local Terminal -> System Explorer. This is the firmware file that you will be flashing to the Catsniffer, copy or move it to your desired location.
7. Flash the firmware into the Catsniffer as described in Flashing firmware from Linux.
8. Press the Reset button RP2040 (Catsniffer 3.x) or Reset SAMD (Catsniffer 2.x - 1.x)
9. We need to read the serial data to read the output generated by the Catsniffer. In Unix/Mac you may use the utility ‘screen’ installed by default in most systems:

$screen <device> <baud rate>

To use the serial port /dev/ttyACM0 and baud rate of 921600 (default baud rate), use the following command:

$screen /dev/ttyACM0 921600

10. You should see a message for every personal tracker detected!

# Hands-on Lab #3: Spoofing personal trackers

## Challenge

Finish the implementation Lab3-Spoofing-Trackers and spoof personal trackers with the Catsniffer

## Objectives

- Learn how to spoof personal trackers
- Learn to craft custom BLE packets
- Write firmware to communicate with devices over BLE

## Walk-Through

1. Import the project Lab2-Detecting-Trackers into Code Composer Studio (File -> Import).

If there are errors related to missing references, go to Project -> Properties -> Resource -> Linked Resources and update their location.

2. Once the project is loaded in Code Composer Studio, get familiar with the folder structure. Browse around the code base. The most important files for our purposes will be in the Application folder.
3. Go to the file Application/Lab3-Spoofing-Trackers.c and locate the function AirtagSpoofer_processGapMessage. Inside this function, you will find the C array airtag_adv_data. This is the structure containing the data used in the advertisement packet.
4. Update the content of this structure to match the content of an advertisement packet.
5. Build the project by clicking on the Build icon on the toolbar
6. Locate the generated .hex file by right-clicking on the project name and then clicking on Show In Local Terminal -> System Explorer. This is the firmware file you will be flashing to the Catsniffer, copy or move it to your desired location.
7. Flash the firmware into the Catsniffer as described in Flashing firmware from Linux.
8. Press the Reset button RP2040 (Catsniffer 3.x) or Reset SAMD (Catsniffer 2.x - 1.x)
9. We need to read the serial data to read the output generated by the Catsniffer. In Unix/Mac you may use the utility ‘screen’ installed by default in most systems:

$screen <device> <baud rate>

To use the serial port /dev/ttyACM0 and baud rate of 921600 (default baud rate), use the following command:

$screen /dev/ttyACM0 921600

10. Use the app Tracker Detect (Android/iOS). Every time you press the reset button, you should see a new personal tracker in the list!

Paulino Calderon - @calderpwn Eduardo Contreras - @foreverwero

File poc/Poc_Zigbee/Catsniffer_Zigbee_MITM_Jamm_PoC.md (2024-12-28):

# CatSniffer MITM ZigBee OTA Server-Client
This PoC are using a ESP32-H2 and ESP32-C6 devices to show how you can sniff the network and in some point you can upload your custom firmware.

## Common ZigBee OTA Process

```mermaid

sequenceDiagram

OTA Client->>OTA Server: Association Request

OTA Server->>OTA Client: Association Response

OTA Server-->OTA Client: Transport Key

OTA Client-->OTA Server: Device Announcement

OTA Client->>OTA Server: Request Key

OTA Server->>OTA Client: Transport Key

OTA Server->>OTA Client: Confirm Key

```

## CatSniffer MITM
### How the OTA update works

```mermaid

sequenceDiagram

participant Catsniffer

OTA Client->>OTA Server: Association Request

Catsniffer-->>OTA Client: Sniff Association Request

OTA Server->>OTA Client: Association Response

Catsniffer-->>OTA Server: Sniff Association Response

OTA Server-->OTA Client: Transport Key

Catsniffer-->>OTA Server: Sniff Transport Key

OTA Client-->OTA Server: Device Announcement

Catsniffer-->>OTA Client: Sniff Device Announcement

OTA Client->>OTA Server: Request Key

Catsniffer-->>OTA Client: Sniff Request Key

OTA Server->>OTA Client: Transport Key

Catsniffer-->>OTA Server: Sniff Transport Key

OTA Server->>OTA Client: Confirm Key

Catsniffer-->>OTA Server: Sniff Confirm Key

```

With the CatSniffer we are listening the channel where the OTA server was found, the main packets that we are focus on, are the `Transport Key` with this we can decrypt the information without using the `Zigbee09` key.

### Start sniffing
Use the Pycatsniffer we can sniff the channel by running:
```bash
python cat_sniffer.py sniff /dev/tty.usbmodem133401 -phy 1 -ch 15 -ff -ws 
```
Where:
- `-phy`: Protocol (IEEE 802.15.4)
- `-ch`: Channel where we want sniff
- `-ff`: Write a FIFO, for use with Wireshark
- `-ws`: Open Wireshark with the FIFO

or, using the extcap:
![[static/Running_catsniffer.gif]]

Once the Wireshark open, we start sniffing the network without a decryption key, a common packets are likes this:
![[static/Wireshar_packet_encrypt.png]]

To decrypt the communication, we can use the `ZigBee09` to configure we can follow the next steps:
- `Wireshark > Preferences > Protocols > ZigBee`
- Edit the *preconfigure keys*
- Add new entry
- Copy the Key value: `5A:69:67:42:65:65:41:6C:6C:69:61:6E:63:65:30:39`
- Add
- Close the protocols window
![[static/Wireshark_Key.gif]]

With this you can now start sniffing!

### View the OTA binary
When we are sniffing the network, if we are in the right moment where the `ZCL OTA: Image Notify` are detected, we can view all the packets with the information of the binary.

![[static/Wireshark_ota_packet.png]]

Our focus packets are the `ZCL OTA: Image Block Response`, this packets has the payload data for our binary information.
![[static/Wireshark_packet_information.png]]
The *Image Data* field, contains the information.

### Getting the OTA data to binary
#### Export the data
Once we had all the data complete we can export the collected data:
- Stop the capture if this still running
- `File -> Export Packet Dissections -> As JSON`
- Save in the directory where you want

![[static/Export_capture_json.gif]]
#### Create the binary
- Open a terminal
- Run the *decoder* with `decoder.py --file /path/to/the/file.json`
- Once the decoder finished, in the directory where this is executed will create two files, the `strings` and the `binary` file.
![[static/Run_decoder.gif]]
#### Compare the information
![[static/ota_binary.png]]
We can compare the binary file with the collected file.

# CatSniffer Targeting OTA Server
This PoC demonstrates how to use the CatSniffer to execute a jamming attack on a network, forcing the client to disconnect and reconnect to our OTA server, where it downloads and installs a custom firmware.

>[!NOTE]
>This PoC is based on the **CatSniffer MITM ZigBee OTA Server-Client**
## How the Attacks  works
This sequence describes a process where a CatSniffer and a jammer are used to disrupt an Over-The-Air (OTA) communication and redirect the client to a fake server for malicious purposes. Here's the description:

1. The **OTA Client** sends an **Association Request** to the legitimate OTA Server, initiating the connection.
2. The **CatSniffer** listens for the **Association Request** from the OTA Client and logs it.
3. The **OTA Server** responds to the client with an **Association Response**.
4. The **CatSniffer** detects the **Association Response** and immediately triggers the jammer, disrupting the communication channel.
5. While the client continues to send **Ping** requests to the legitimate server, the server issues a **Disassociation Request** to terminate the communication and closes the network.
6. After losing connection, the **OTA Client** searches for other available networks by sending a **Beacon Request**.
7. The **Fake Server** responds with a **Beacon Response**, signaling that it is available for the client to connect.
8. The **OTA Client** sends an **Association Request** to the **Fake Server**, starting the process of connecting to it, potentially leading to the installation of malicious firmware.

This workflow illustrates how jamming and packet sniffing are used to hijack a client's network connection and force it to communicate with a rogue server.

```mermaid

sequenceDiagram

participant Catsniffer
participant Fake Server
OTA Client->>OTA Server: Association Request
Catsniffer-->>OTA Client: Sniff Association Request
OTA Server->>OTA Client: Association Response
Catsniffer-->>OTA Server: Detect Association Response
Catsniffer-->>OTA Server: Start Jamming
OTA Client-->OTA Server: Ping
OTA Client-->OTA Server: Ping
OTA Client-->OTA Server: Ping
OTA Server-->OTA Server: Disassociation Request
OTA Server-->OTA Server: Close Network
OTA Client->>Fake Server: Beacon Request
Fake Server->>OTA Client: Beacon Response 
OTA Client->>Fake Server: Association Request
Fake Server->>OTA Client: Association Response

```

## The jammer
For this test I used a ESP32-WROOM and custom firmware with two NRF24 modules.

## Starting the attack
To start the attack we use the `Catbee` tool:
```shell
# Clone the repo
git clone https://github.com/JahazielLem/catbee.git
cd catbee
pip install -r requirements.txt
```
Then you need to specify the path to the CatSniffer, the Channel to sniff and the Jammer path
```shell
python3 catbee.py -cs /dev/tty.usbmodem1101 -csch 13 -jm /dev/tty.usbserial-0001 -jmb 115200
```
Where:
- `-cs`: Path to the comport of catsniffer
- `-csch`: Channel where catsniffer will sniff to find the `Association Request`
- `-jm`: Path to the comport of the jammer
- `-jmb`: Baudrate of the jammer if this work in a different value than `921600`

![[static/sending_attack.gif]]

Once the Catbee detect the `Association Response` start the jamming attack to the channel, so our rogue server can responde to the Client and the connection will be establish.

![[static/Finished.gif]]

>[!NOTE]
>I create my custom firmware to demonstrate how the OTA was loaded successfully

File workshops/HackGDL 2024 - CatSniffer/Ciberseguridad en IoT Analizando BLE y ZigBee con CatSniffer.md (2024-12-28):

# Content
- [Conociendo el Hardware](#conociendo-el-hardware)
  - [Hardware - CatSniffer](#hardware---catsniffer)
  - [Hardware - CatSniffer - Features](#hardware---catsniffer---features)
  - [Hardware - CatSniffer - Funcionamiento](#hardware---catsniffer---funcionamiento)
- [Bluetooth Low Energy (BLE)](#bluetooth-low-energy-ble)
  - [BLE - Conociendo el protocolo](#ble---conociendo-el-protocolo)
  - [BLE - Generic Access Profile (GAP)](#ble---generic-access-profile-gap)
  - [BLE - Generic Attribute Profile (GATT)](#ble---generic-attribute-profile-gatt)
- [PyCatSniffer](#pycatsniffer)
  - [PyCatSniffer - Demo - Sniffeando Conexion BLE](#pycatsniffer---demo---sniffeando-conexion-ble)
  - [PyCatSniffer - PCAP - BLE](#pycatsniffer---pcap---ble)
- [ZigBee](#zigbee)
  - [ZigBee - Arquitectura](#zigbee---arquitectura)
  - [ZigBee - Application Profiles](#zigbee---application-profiles)
  - [ZigBee - Device Descriptor](#zigbee---device-descriptor)
  - [ZigBee - Cluster Identifiers](#zigbee---cluster-identifiers)
  - [ZigBee - Network Security Model](#zigbee---network-security-model)
  - [PyCatSniffer - Demo - Sniffeando Conexion ZigBee Centralizada](#pycatsniffer---demo---sniffeando-conexion-zigbee-centralizada)
  - [PyCatSniffer - Demo - Sniffeando Conexion ZigBee Distribuida](#pycatsniffer---demo---sniffeando-conexion-zigbee-distribuida)
  - [PyCatSniffer - Demo - PCAP - Analizando la informacion](#pycatsniffer---demo---pcap---analizando-la-informacion)
- [HackGDL](#hackgdl)
- [Bibliografía](#bibliografía)

# Conociendo el Hardware

## Hardware - CatSniffer
CatSniffer es un dispositivo multiprotocolo y multibanda creado para sniffear, comunicar y atacar dispositivos IoT. Esta placa es como una navaja suiza de los investigadores, desarrolladores y entusiastas.

![[static/CatSniffer_Board.jpeg]]

## Hardware - CatSniffer - Features
CatSniffer puede operar en 3 diferentes tecnologías:
- Lora
- Sub 1 GHz
- 2.4 GHz
Protocolos soportados:
- Thread
- ZigBee
- Bluetooth 5 Low Energy (BLE)

>[!NOTE]
>Para mas informacion revisar el repositorio del [proyecto](https://github.com/ElectronicCats/CatSniffer.

## Hardware - CatSniffer - Funcionamiento

![[static/CatSniffer_BlockDriagram.png]]

# Bluetooth Low Energy (BLE)
Bluetooth Low Energy es diseñado para la operación en dispositivos de bajo consumo, su versatilidad permite crear múltiples topologías de comunicación:
- **Point-To-Point**: Es utilizada típicamente en la comunicación directa entre dos dispositivos
- **Broadcast**: Se utiliza para enviar información sin establecer una conexión previa
- **Mesh**: Todos los dispositivos están interconectados

![[static/BLE_Topology.png]]

## BLE - Conociendo el protocolo
![[BLE_Channels.png]]

Ble opera en la banda de los 2.4 GHz, el rango de operación es de 2400 MHz a 2483.5 MHz dividido en 40 canales, dentro del rango 3 canales son de *Advertising* (ADV).
- 37, 38, 39
- En estos canales los dispositivos mandan un "ping"
- Estos paquetes son conocidos como Beacons

![[static/BLE_Communication_Diagram.png]]

Los dispositivos BLE solo mandan paquetes de advertising cuando necesitan conectarse e intercambiar información, el dispositivo escucha tambien llamado *central device*, responde a un paquete de advertising con un **SCAN Request**, la respuesta al *scan request* y la misma estructura que el paquete de ADV.

##  BLE - Conociendo el protocolo - Paquete BLE

| Preamble | Access Address | Protocol Data Unit (PDU) | CRC |
| --- | --- | --- | --- |
| 1 Byte | 4 Byte | 2-257 Bytes | 3 Bytes |
**Preamble**: Permite al receptor sincronizar de manera precisa la frecuencia de la señal
**Access Address**: Es usado por el receptor para diferencia señal de ruido y determinar el paquete recibido
**CRC**: Este valor es calculado por el transmisor usando el valor de los demas bits del paquete, se utiliza para la deteccion de errores.

> El campo de **PDU** puede ser diferentes PDU's dependiendo en como el dispositivo BLE es usado.

##  BLE - Conociendo el protocolo - Paquete BLE
**Directed - Undirected**:
- El tipo Directed ADV acepta solicitudes de conexion de un dispositivo conocido.
- Undirected ADV acepta conexiones de cualquier dispositivo
**Connectable - No connectable**:
- Determina si el dispositivo ADV acepta conexiones o no.

**Legacy**: Son las unidades de datos que bluetooth tiene por defecto en cualquiere dispositivo.
- ADV_IND: Conectable, escaneable, no dirigido ADV
- ADV_DIRECT_IND: Conectable dirigido ADV
- ADV_NONCONN_IND: No conectable, no escaneable ADV
- ADV_SCAN_IND: Escaneable, no dirigido ADV

**Escaneado**:
Son las unidades de datos relacionados al proceso de intercomunicacion entre el dispositivo central y el dispositivo final.
- SCAN_REQ
- SCAN_RSP
- CONNECT_IND

![[static/Wireshark_BLE_Capture.png]]

![[static/BLE_Capture_frame.png]]

## BLE - Generic Access Profile (GAP)
El GAP define cómo se pueden conectar con otros dispositivos, comunicar y estar visibles para su descubrimiento, un dispositivo periférico solo se puede conectar a un dispositivo central, el dispositivo central se puede conectar a los dispositivos perifericos que este soporte.
Por cada conexion el dispositivo periferico envia pquetes de ADV en intervalos de tiempo.

> Todos los dipositivos BLE tienen *Generic Access Profile (GAP)*

![[static/BLE_GAP_Diagrama.png]]
## BLE - Generic Attribute Profile (GATT)
El GATT define el formato y como el dispositivo debe transferir información este nos muestra como la informacion es slmacenada, agrupada y modificada.
El GATT lista las **caracteristicas del dispositivo, descriptores y servicios**
> Los servicios son mostrados como un valor de 16 o 32 bits

Una *caracteristica* es un valor enviado entre el dispositivo central y el periferico, las caracteristicas contienen *descriptores*, estos proveen informacion adicional.

![[static/BLE_GATT_Diagrama.png]]

# PyCatSniffer
PyCatSniffer es una herramienta multiplataforma escrita en Python, compatible con el firmware *Packet Sniffer TI*, permite exportar la informacion en diferentes formatos y crear un pipeline con Wireshark.
Soporta diferentes protocolos:
- BLE
- ZigBee
- Thread

> Para mas informacion revisar el [repo](https://github.com/ElectronicCats/CatSniffer-Tools)

En Wireshar podemos ver la comunicacion entre los dispositivos Bluetooth, realizar el seguimiento cuando encuentra una conexion en el mismo canal que estamos sniffeando.
Al usar Wireshark nos permite realizar tratamiento de datos como:
- Filtrar informacion
- Colorizar conversaciones
- Exportar informacion

## PyCatSniffer - Demo - Sniffeando Conexion BLE

PyCatSniffer - Demo - Sniffeando Conexion BLE (https://www.youtube.com/watch?v=oOcJloXW9dI)

## PyCatSniffer - PCAP - BLE
En el siguiente PCAP podemos ver que encontramos un paquete de datos de **CONNECT_IND**, esto indica que una conexion ha sido solicitada y establecida entre un dispositivo BLE y un central device.
![[static/Wireshar_PCAP_BLE_Capture.png]]

Dentro del PCAP podemos encontrar un paquete con parametros de *Security Request*, esta paquete nos indica que el dispositivo solicitada una conexion, en la estructura de datos del frame podemos observar los siguientes datos:
- Secure Connection Flag: True
- MITM Flag: True

El MITM hace referencia a *Man-In- The-Middle*, esta flag se utiliza para securizar la conexion haciendo que el dispositivo que envia no comparta la key de emparejamiento.

> Si uno de los dos dispositivos que buscan realizar un emparejamiento, no tienen la bandera de MITM, se puede obtener la clave de emparejamiento.

![[static/Wireshar_PCAP_BLE_Capture_Flipper.png]]

# ZigBee
Zigbee es un protocolo de comunicación desarrollado por Zigbee Alliance, basado en el estándar IEEE 802.15.4. Se destaca por su eficiencia energética, lo que lo hace ideal para aplicaciones IoT donde se requiere un bajo consumo de energía. Su topología tipo Mesh permite que los dispositivos se comuniquen entre sí de manera redundante, lo que aumenta la confiabilidad y la cobertura de la red. Con la capacidad de admitir hasta 65535 nodos, Zigbee es escalable y puede adaptarse a una amplia gama de aplicaciones. Además, utiliza un sólido cifrado AES de 128 bits para garantizar la seguridad de las comunicaciones.

![[static/ZigBee_Layers.png]]

## ZigBee - Arquitectura
**PHY Layer**: Es la capa donde el transmisor de RF envia los bytes en base a la frecuencia de la region.
- Existen tres regiones:
	- Global: 2.4 GHz
	- America: 915 MHz
	- Europa: 868 MHz
- 2.4 GHz opera en 16 canales

**MAC Layer**: Es la capa encargada de asignar y administrar las conexiones de los dispositivos.

**Coordinador**: Es el dispositivo encargado de administrar la red, el crea las conexiones entre los dispositivos, intercambia las claves de red.
**Router**: Se encarga de repetir la senal de los end device al coordinador, este dispositivo se utiliza para extender el alcance de la red y distribuir la red.
**End Device**: Tambien conocidos como dispositvos de funcion reducida, solo envia senales, estos dispositivios pueden ser los sensores, actuares, etc.

![[static/ZigBee_Red.png]]

## ZigBee - Application Profiles
Es una coleccion de descriptores del dispositivo, permite enviar comandos, solicitar informacion y procesar comandos y solicitudes, define el tipo de mensaje que se enviara.

![[static/ZigBee_ApplicationProfile.png]]

## ZigBee - Device Descriptor
Es una descripcion del dispositivo entre una *application profile*, define la informacion basica del dispositivo, tiene un identificador unicao que es intercambiado como parte del proceso de descubrimiento.

## ZigBee - Cluster Identifiers
Es una descripcion del dispositivo entre una *application profile*, representa una coleccion de atributos y comandos que son usados para controlar aspectos del dispositivo, cada cluster identifier soporta una pila de atributos.

| ZigBee device Group | ZigBee device ID | Description |
| --- | --- | --- |
| Generic | 0x0000 | ON/OFF Switch |
| | 0x0001 | Level Control Switch |
| | 0x0002 | ON/OFF Ouput |
| Lighting | 0x0100 | ON/OFF Light |
| | 0x0101 | Diammable light |
| Intruder Alarm Systems | 0x0400 | IAS Control and Indication |
| | 0x0402 | IAS Zone |

## ZigBee - Network Security Model
### Centralizado
Solo el coordinador/trust center puede iniciar redes centralizadas, cuando un nodo se une, recibe la llave de red proporcionada por el trust center y establecen una llave de emparejamiento unica.

> Los nodos pueden soportar instalar codigos. Esto corresponde a instalar en el dispositivo una llave unica diferente a la utilizada al incio de la conexion.

### Distribuido
Este tipo de red no tiene nodo central/trust center, el router es el encargado de comenzar redes distribuidas, los nodos envias y reciben las llaves de red.
En esta comunicacion la llave de red es compartida por cada end device hacia el nodo en donde se realice la conexion.

## PyCatSniffer - Demo - Sniffeando Conexion ZigBee Centralizada

PyCatSniffer - Demo - Sniffeando Conexion ZigBee Centralizada (https://www.youtube.com/watch?v=Nl8MkhRTczk)

## PyCatSniffer - Demo - Sniffeando Conexion ZigBee Distribuida

PyCatSniffer - Demo - Sniffeando Conexion ZigBee Centralizada (https://www.youtube.com/watch?v=eAaMv7jrr0I)

## PyCatSniffer - Demo - PCAP - Analizando la informacion

![[static/ZigBee_PCAP.png]]

Dentro de la informacion recopilada encontramos informacion que nos ayudan a saber donde encontramos los valores para escribir en los dispositivos finales. En el PCAP podemos notar la siguiente informacion:
- **Transport Key**: Clave de Red distribuida
- **Device Profile**:
	- Cluster: La ubicacion donde se almacena los valores del dispositivo
	- Profile: El tipo de application profile del dispositivo
	- Source Endpoint: Los dispositivos cuentan con un ruta donde podemos apuntar para escribir o leer un valor
	- Attribute Field: Ubicacion del valor a leer
	- Data type: Tipo de dato que podemos utilizar sobre el atributo

Con esa informacion podemos obtener los valores y posteriormente podemos escribir en ellos mandando la informacion con *ZCL* (ZigBee Cluster Library).

# HackGDL
[Slides de la conferencia](https://docs.google.com/presentation/d/1V1vNgGP26OVy4PmkgJffvl4cvWKJ1ykW/edit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)

# Bibliografía
- [Practical IoT Hacking ](https://nostarch.com/practical-iot-hacking)

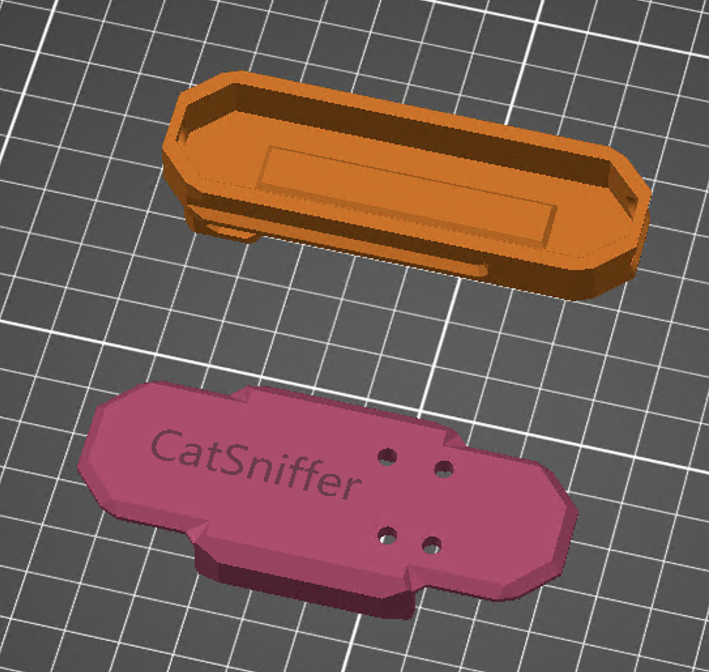
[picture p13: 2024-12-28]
cases/case-catsniffer-text/front.png

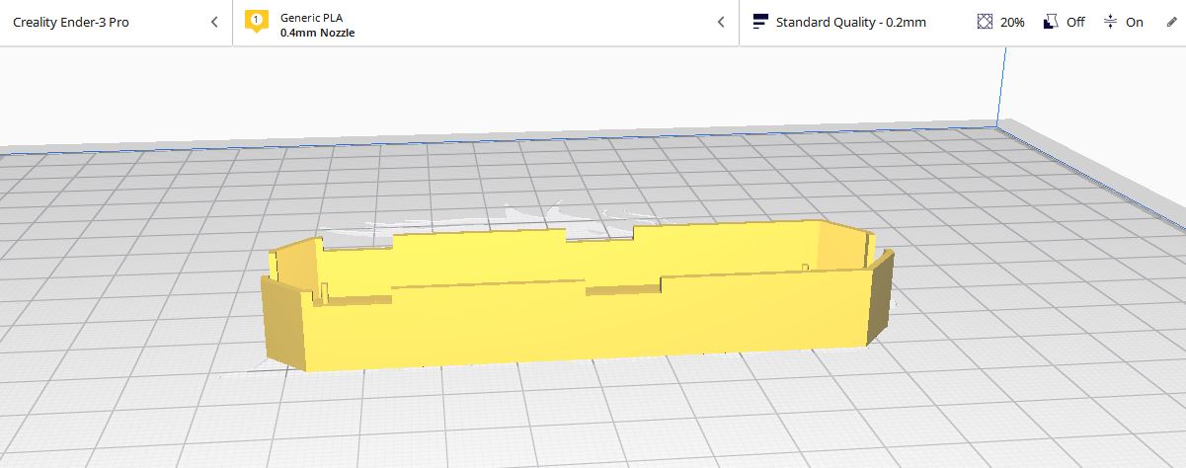
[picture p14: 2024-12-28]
cases/case-mamalon-v1/sc_case.jpg

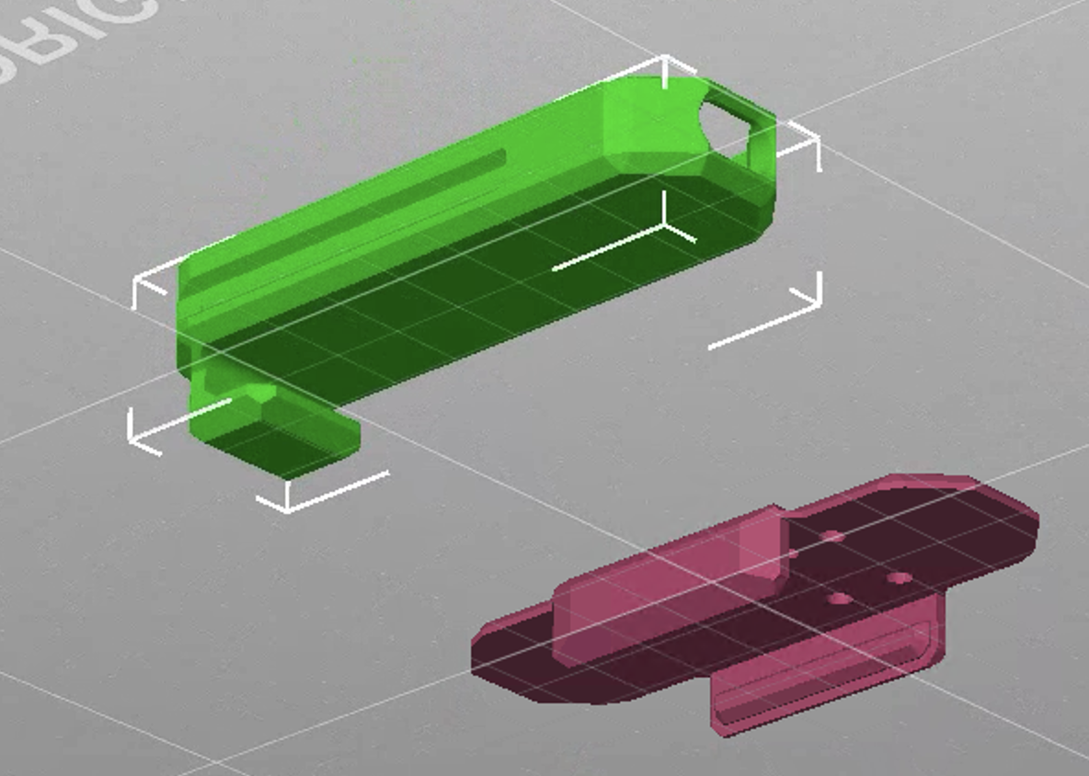
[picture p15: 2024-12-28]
cases/case-catsniffer-text/under.png

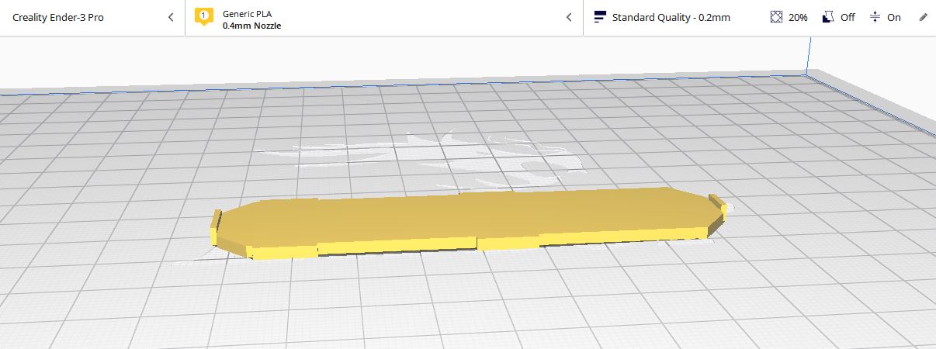
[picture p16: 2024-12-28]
cases/case-mamalon-v1/sc_top.jpg

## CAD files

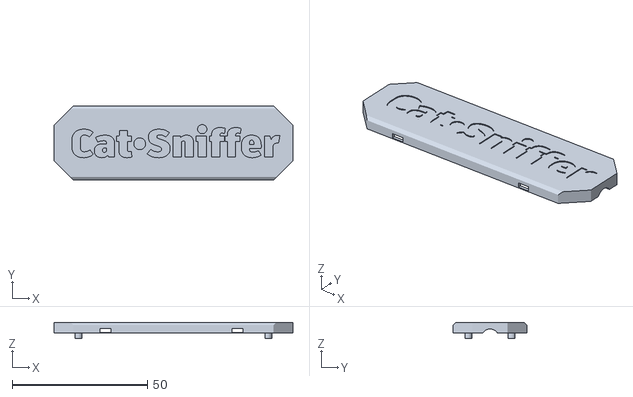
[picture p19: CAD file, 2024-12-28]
cases/basic-case/CatSniffer-case-top.stl
88.2 x 27.2 x 6.00

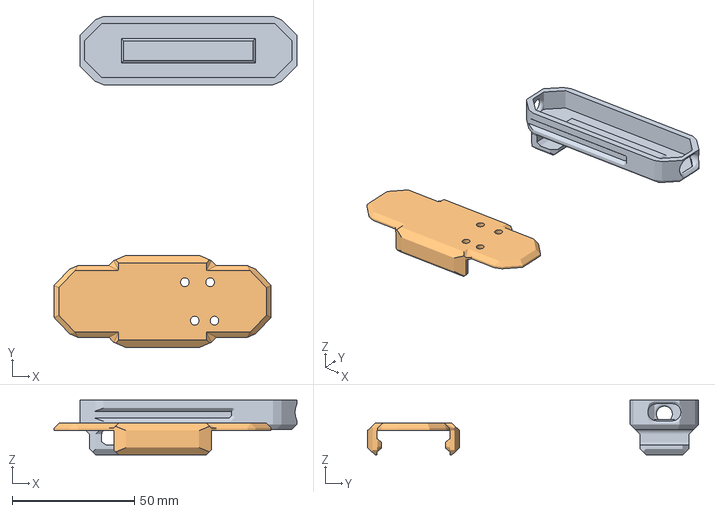
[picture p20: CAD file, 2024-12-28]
cases/case-catsniffer-text/Case-CatSniferText.3mf
99.6 x 135.7 x 22.5 mm
CatSnifer-Base.stl
CatSnifer-Tapa.stl

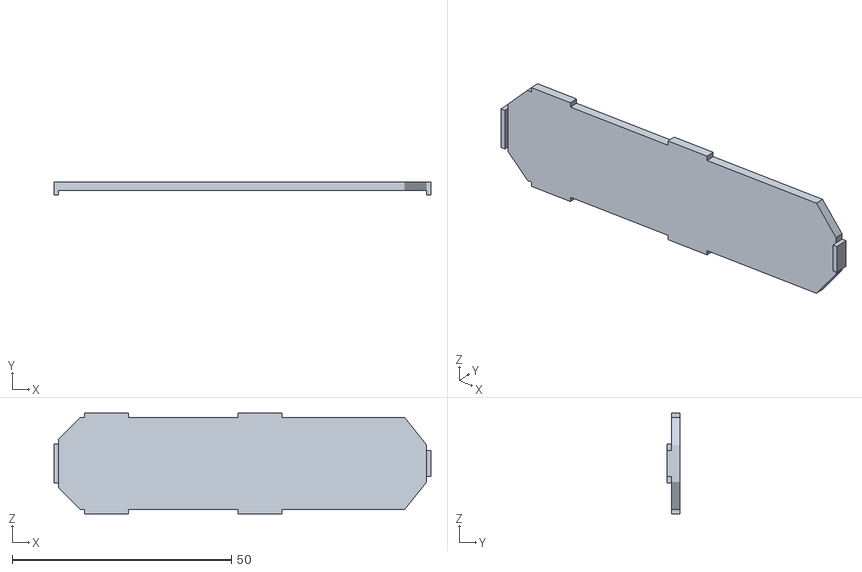
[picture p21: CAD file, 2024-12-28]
cases/case-mamalon-v1/sc_top.stl
86.0 x 3.00 x 23.0

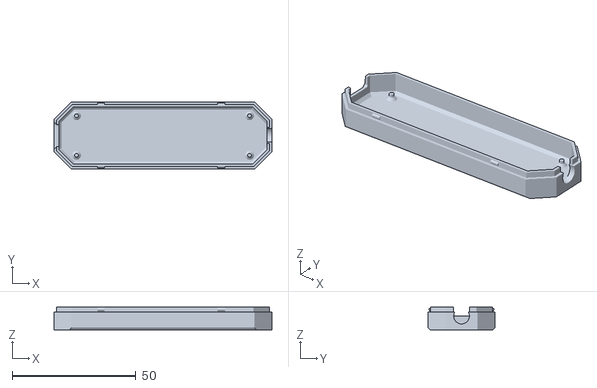
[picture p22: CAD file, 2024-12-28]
cases/basic-case/CatSniffer-case-bottom.stl
88.2 x 27.2 x 9.25

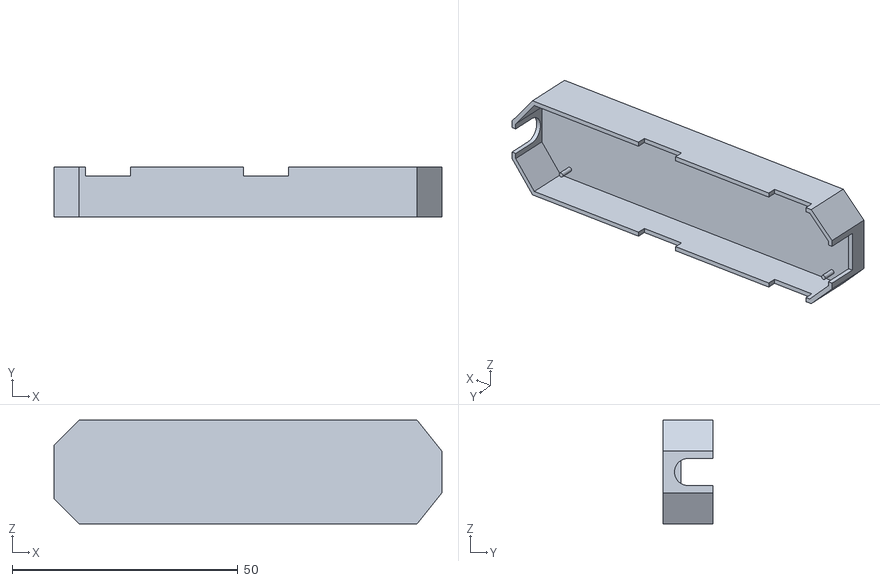
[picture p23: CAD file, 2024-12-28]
cases/case-mamalon-v1/sc_case.stl
86.0 x 11.0 x 23.0

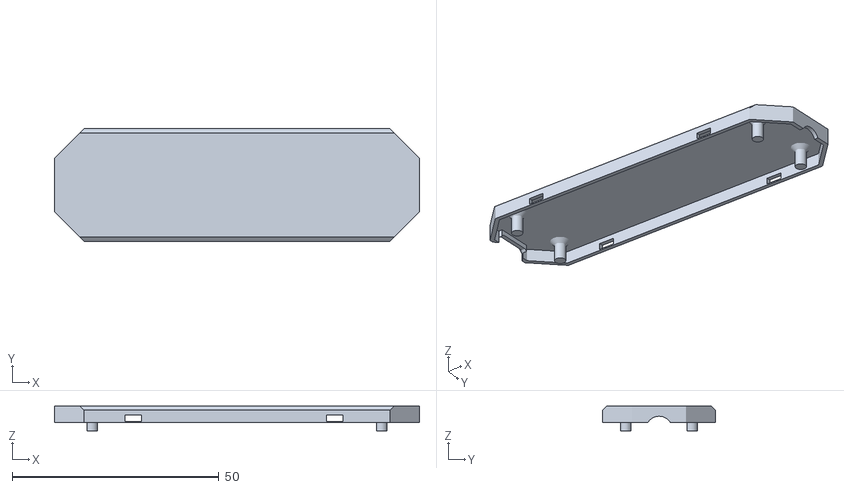
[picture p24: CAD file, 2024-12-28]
cases/basic-case/CatSniffer-case-top-flat.stl
88.2 x 27.2 x 6.00

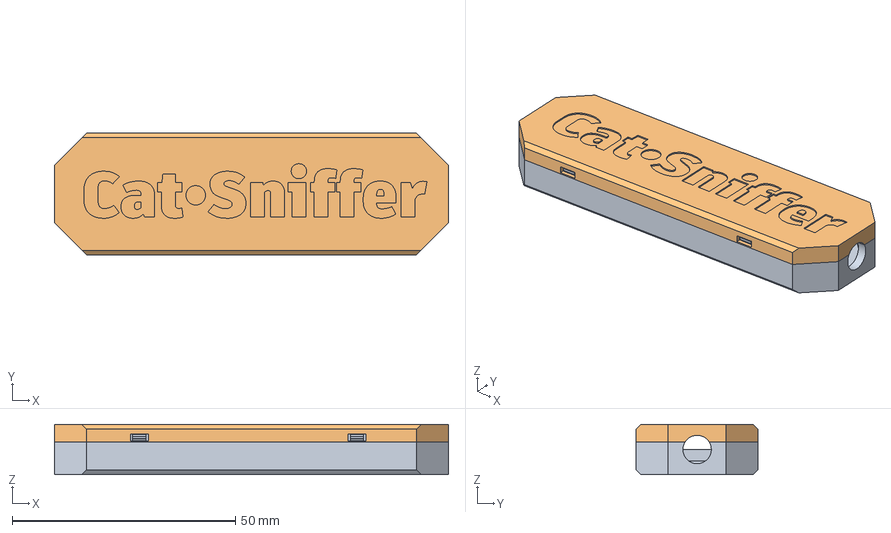
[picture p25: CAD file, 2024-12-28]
cases/basic-case/CatSniffer-case.step
88.2 x 27.2 x 11.2 mm

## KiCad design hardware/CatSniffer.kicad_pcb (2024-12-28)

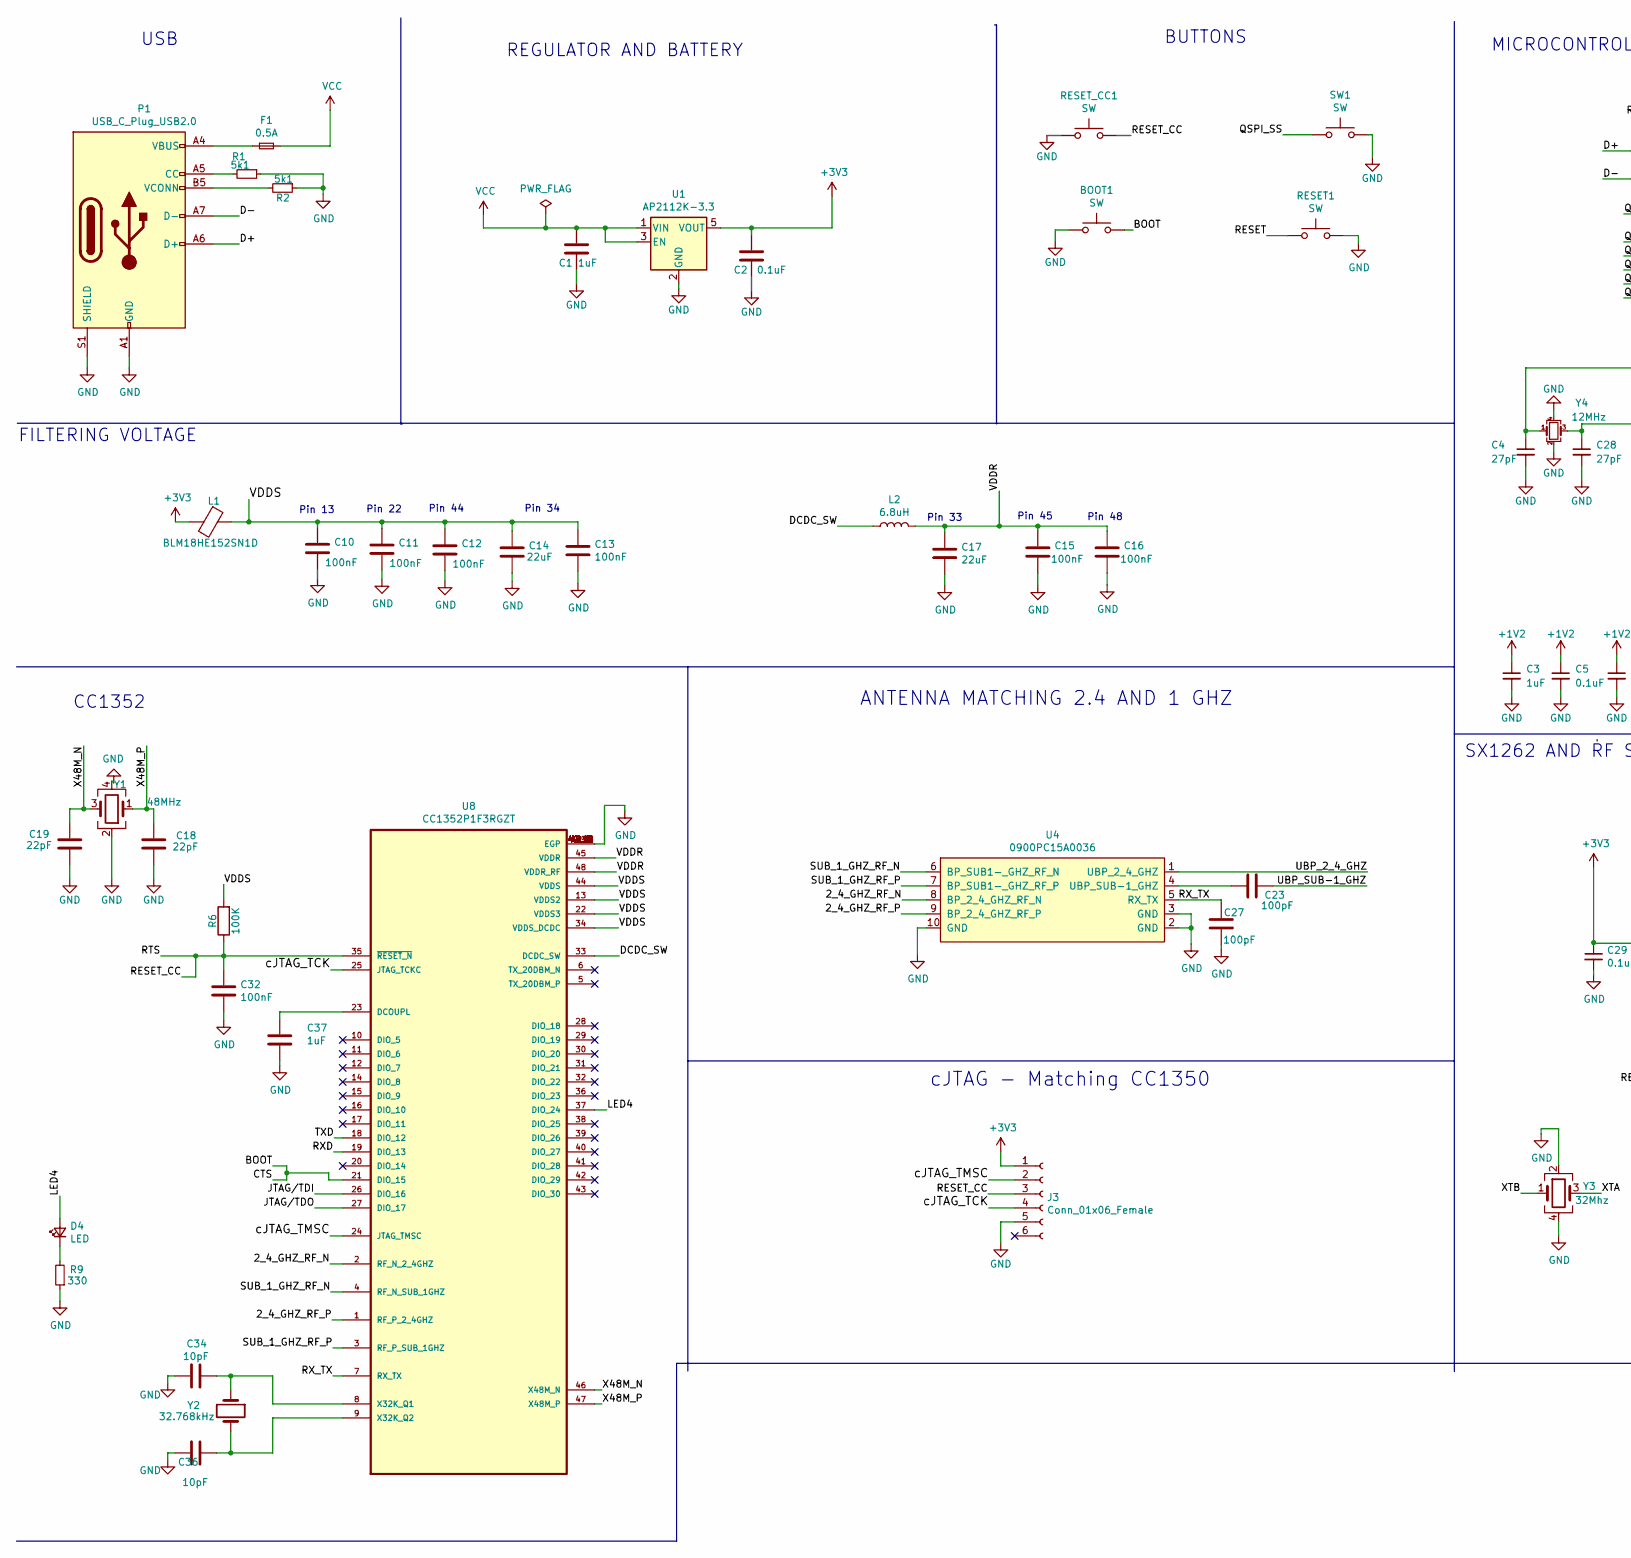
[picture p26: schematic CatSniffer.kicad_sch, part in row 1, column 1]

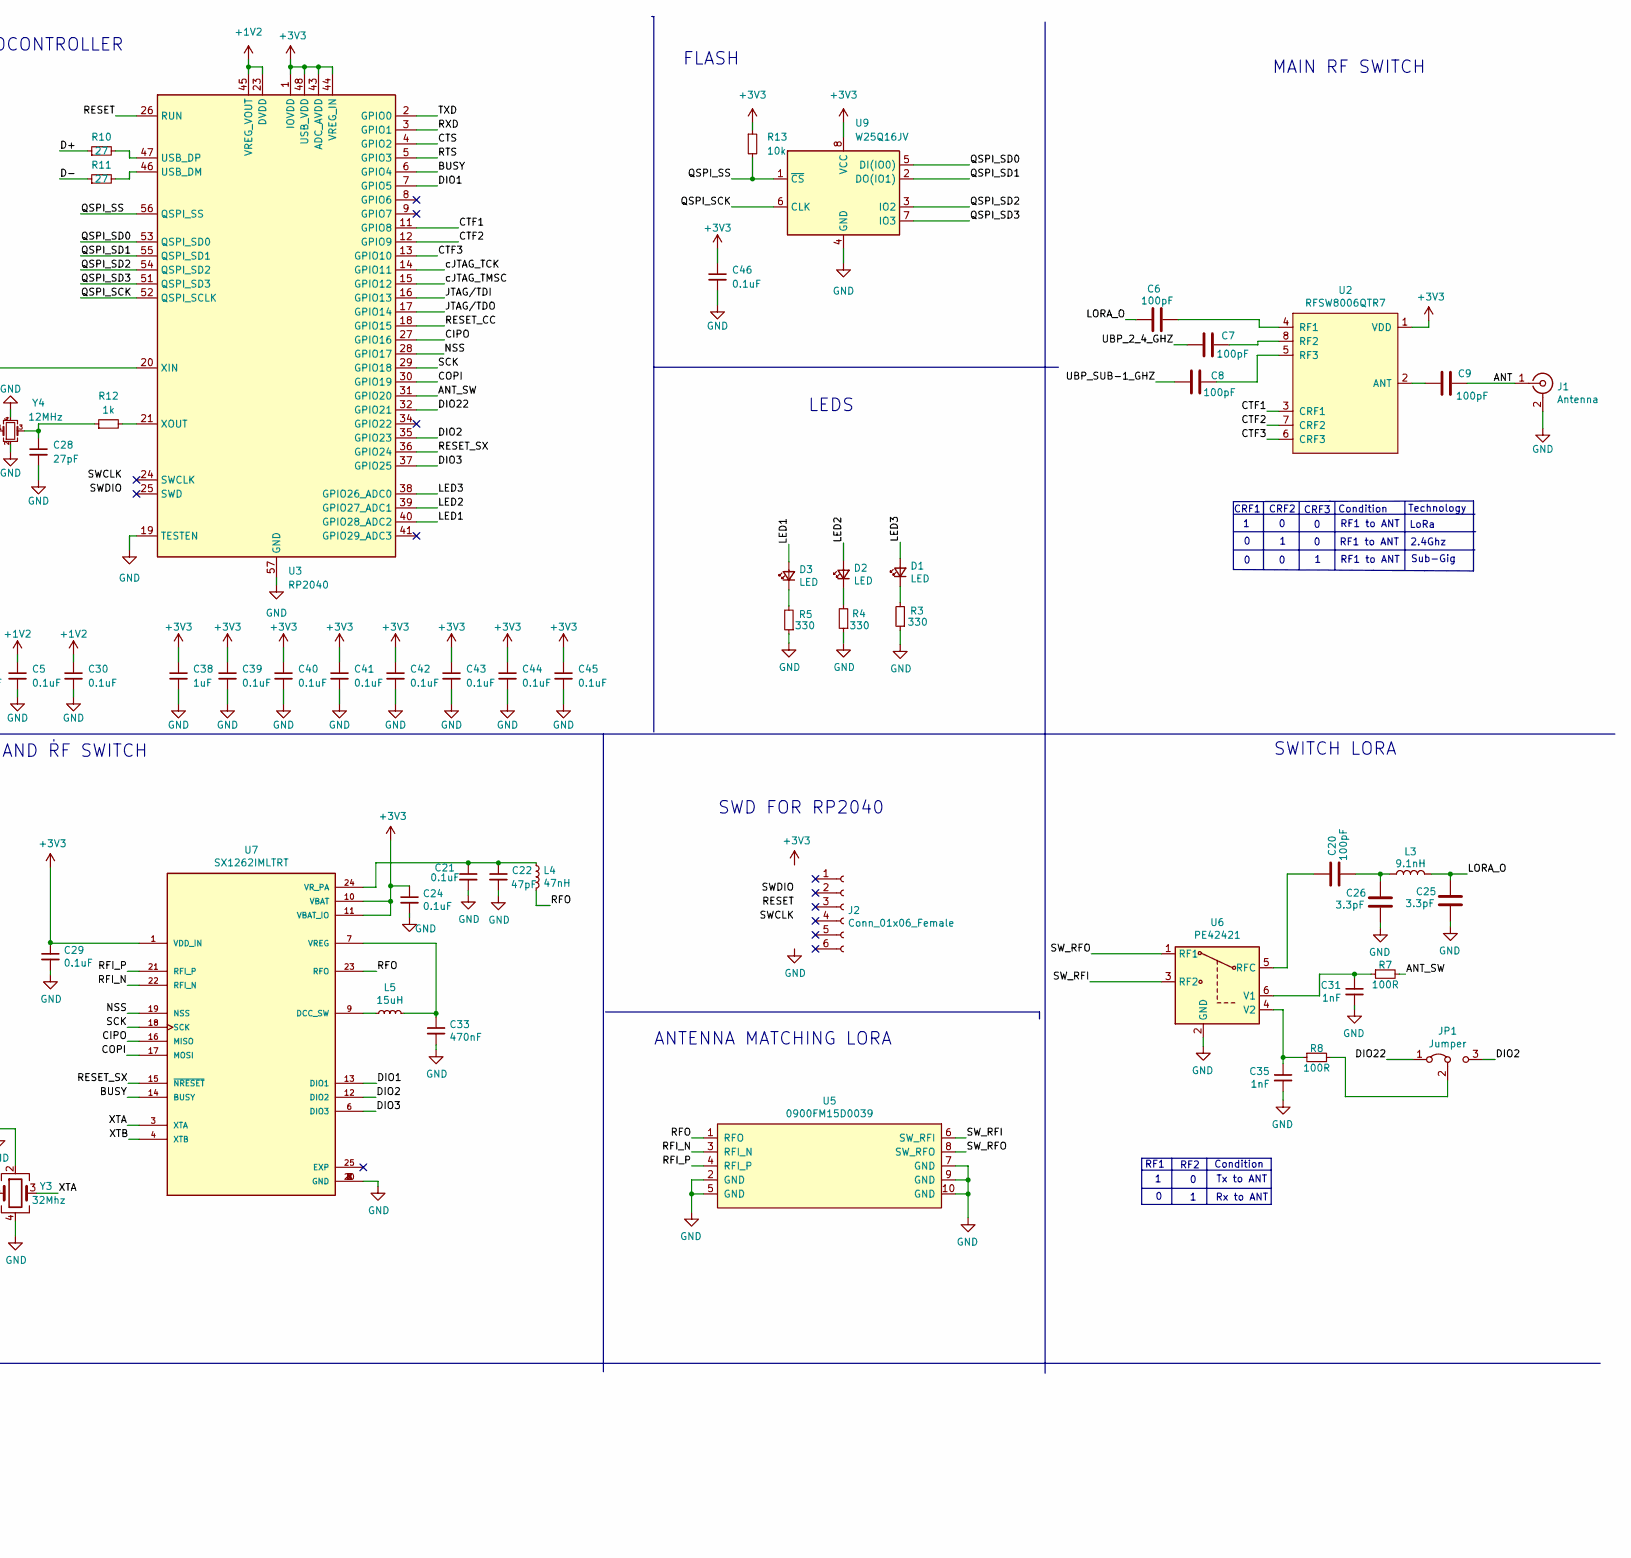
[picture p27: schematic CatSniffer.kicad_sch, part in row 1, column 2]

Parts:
BOOT1: SW; TS1088R02026; LCSC# C455281
C1, C37: 1uF; C_0603_1608Metric; LCSC# C108343
C2, C21, C24, C29: 0.1uF; C_0603_1608Metric; LCSC# C14663
C3, C38: 1uF; C_0402_1005Metric; Mouser# 963-MSRLJ103SB5105MF
C4, C28: 27pF; C_0402_1005Metric; Mouser# 81-GJM1555C1H270FB1D
C5, C30, C39, C40, C41, C42, C43, C44, C45, C46: 0.1uF; C_0402_1005Metric; Mouser# 963-MSAST105SB7104KF
C6, C7, C8, C9, C20, C23, C27: 100pF; C_0603_1608Metric; LCSC# C14858
C10, C11, C12, C13, C15, C16, C32: 100nF; C_0402_1005Metric; LCSC# C162179
C14, C17: 22uF; C_0603_1608Metric; LCSC# C109447
C18, C19: 22pF; C_0603_1608Metric; LCSC# C170132
C22: 47pF; C_0603_1608Metric; LCSC# C519486
C25, C26: 3.3pF; C_0603_1608Metric; LCSC# C162225
C31, C35: 1nF; C_0603_1608Metric; LCSC# C1588
C33: 470nF; C_0603_1608Metric; LCSC# C170149
C34, C36: 10pF; C_0603_1608Metric; LCSC# C472782
D1, D2, D3, D4: LED; LED_0603_1608Metric_Pad1.05x0.95mm_HandSolder; LCSC# C524045
F1: 0.5A; Fuse_0805_2012Metric_Pad1.15x1.40mm_HandSolder; Mouser# 594-MFU0805FF00500P1
J1: Antenna; SMA_EDGE; LCSC# C530661
J2, J3: Conn_01x06_Female; Tag-Connect_TC2030-IDC-NL_2x03_P1.27mm_Vertical
JP1: Jumper; SolderJumper-3_P1.3mm_Bridged12_RoundedPad1.0x1.5mm_NumberL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
L1: BLM18HE152SN1D; L_0603_1608Metric; Mouser# BLM18HE152SN1D
L2: 6.8uH; L_0603_1608Metric; Mouser# MLZ1608M6R8WT000
L3: 9.1nH; L_0603_1608Metric; LCSC# C395094
L4: 47nH; L_0603_1608Metric; LCSC# C578001
L5: 15uH; L_0603_1608Metric; LCSC# C57838
P1: USB_C_Plug_USB2.0; C393939; LCSC# C709357
R1, R2: 5k1; R_0603_1608Metric; LCSC# C319561
R3, R4, R5, R9: 330; R_0603_1608Metric; LCSC# C408915
R6: 100K; R_0603_1608Metric; LCSC# C179820
R7, R8: 100R; R_0603_1608Metric; LCSC# C700506
R10, R11: 27; R_0402_1005Metric; Mouser# 755-ESR01MZPF27R0
R12: 1k; R_0402_1005Metric; Mouser# 594-MCS0402MD1001DE0
R13: 10k; R_0402_1005Metric; Mouser# 594-MCS04020D1002BE0
RESET1: SW; TS1088R02026; LCSC# C455281
RESET_CC1: SW; TS1088R02026; LCSC# C455281
SW1: SW; TS1088R02026; LCSC# C455281
U1: AP2112K-3.3; SOT-23-5; Mouser# 865-XC6210B332MR-G
U2: RFSW8006QTR7; SON50P200X200X90-9N; Mouser# 772-RFSW8006QTR7
U3: RP2040; QFN-56-1EP_7x7mm_P0.4mm_EP3.2x3.2mm; LCSC# C2040
U4: 0900PC15A0036; 0900FM15D0039E; Mouser# 609-0900PC15A0036E
U5: 0900FM15D0039; 0900FM15D0039E; Mouser# 609-0900FM15D0039E
U6: PE42421; SOT-363_SC-70-6; Mouser# 81-PE42421SCAA-Z
U7: SX1262IMLTRT; QFN-24-1EP_4x4mm_P0.5mm_EP2.65x2.65mm; Mouser# 947-SX1262IMLTRT
U8: CC1352P1F3RGZT; VQFN-48-1EP_7x7mm_P0.5mm_EP5.15x5.15mm_ThermalVias; Mouser# 595-CC1352P1F3RGZT
U9: W25Q16JV; W25Q16JVUUIQ; Mouser# 454-W25Q16JVUUIQTR
Y1: 48MHz; Crystal_SMD_3225-4Pin_3.2x2.5mm; LCSC# C389928
Y2: 32.768kHz; Crystal_SMD_2012-2Pin_2.0x1.2mm; LCSC# C97603
Y3: 32Mhz; Crystal_SMD_2520-4Pin_2.5x2.0mm; LCSC# C255969
Y4: 12MHz; Crystal_SMD_3225-4Pin_3.2x2.5mm; LCSC# C2848217

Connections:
+1V2: C3.1, C5.1, C30.1, U3.23 (DVDD), U3.45 (VREG_VOUT), U3.50 (DVDD)
+3V3: C2.2, C24.1, C29.1, C38.1, C39.1, C40.1, C41.1, C42.1, C43.1, C44.1, C45.1, C46.1, J3.1, L1.2, R13.1, U1.5 (VOUT), U2.1 (VDD), U3.1 (IOVDD), U3.10 (IOVDD), U3.22 (IOVDD), U3.33 (IOVDD), U3.42 (IOVDD), U3.43 (ADC_AVDD), U3.44 (VREG_IN), U3.48 (USB_VDD), U3.49 (IOVDD), U7.1 (VDD_IN), U7.10 (VBAT), U7.11 (VBAT_IO), U9.8 (VCC)
/2_4_GHZ_RF_N: U4.8 (BP_2_4_GHZ_RF_N), U8.2 (RF_N_2_4GHZ)
/2_4_GHZ_RF_P: U4.9 (BP_2_4_GHZ_RF_P), U8.1 (RF_P_2_4GHZ)
/ANT: C9.2, J1.1 (In)
/ANT_SW: R7.2, U3.31 (GPIO20)
/BOOT: BOOT1.2, U3.4 (GPIO2), U8.21 (DIO_15)
/BUSY: U3.6 (GPIO4), U7.14 (BUSY)
/CIPO: U3.27 (GPIO16), U7.16 (MISO)
/COPI: U3.30 (GPIO19), U7.17 (MOSI)
/CTF1: U2.3 (CRF1), U3.11 (GPIO8)
/CTF2: U2.7 (CRF2), U3.12 (GPIO9)
/CTF3: U2.6 (CRF3), U3.13 (GPIO10)
/D+: P1.A6 (D+), R10.1
/D-: P1.A7 (D-), R11.1
/DCDC_SW: L2.1, U8.33 (DCDC_SW)
/DIO1: U3.7 (GPIO5), U7.13 (DIO1)
/DIO2: JP1.3 (B), U3.35 (GPIO23), U7.12 (DIO2)
/DIO3: U3.37 (GPIO25), U7.6 (DIO3)
/DIO22: JP1.1 (A), U3.32 (GPIO21)
/JTAG/TDI: U3.16 (GPIO13), U8.26 (DIO_16)
/JTAG/TDO: U3.17 (GPIO14), U8.27 (DIO_17)
/LED1: D3.2 (A), U3.40 (GPIO28_ADC2)
/LED2: D2.2 (A), U3.39 (GPIO27_ADC1)
/LED3: D1.2 (A), U3.38 (GPIO26_ADC0)
/LED4: D4.2 (A), U8.37 (DIO_24)
/LORA_O: C6.1, C25.1, L3.1
/NSS: U3.28 (GPIO17), U7.19 (NSS)
/QSPI_SCK: U3.52 (QSPI_SCLK), U9.6 (CLK)
/QSPI_SD0: U3.53 (QSPI_SD0), U9.5 (DI(IO0))
/QSPI_SD1: U3.55 (QSPI_SD1), U9.2 (DO(IO1))
/QSPI_SD2: U3.54 (QSPI_SD2), U9.3 (IO2)
/QSPI_SD3: U3.51 (QSPI_SD3), U9.7 (IO3)
/QSPI_SS: R13.2, SW1.1, U3.56 (QSPI_SS), U9.1 (~CS)
/RESET: RESET1.1, U3.26 (RUN)
/RESET_CC: C32.1, J3.3, R6.1, RESET_CC1.2, U3.5 (GPIO3), U3.18 (GPIO15), U8.35 (~RESET_N)
/RESET_SX: U3.36 (GPIO24), U7.15 (~NRESET)
/RFI_N: U5.3 (RFI_N), U7.22 (RFI_N)
/RFI_P: U5.4 (RFI_P), U7.21 (RFI_P)
/RFO: L4.2, U5.1 (RFO), U7.23 (RFO)
/RXD: U3.3 (GPIO1), U8.19 (DIO_13)
/RX_TX: C27.2, U4.5 (RX_TX), U8.7 (RX_TX)
/SCK: U3.29 (GPIO18), U7.18 (SCK)
/SUB_1_GHZ_RF_N: U4.6 (BP_SUB1-_GHZ_RF_N), U8.4 (RF_N_SUB_1GHZ)
/SUB_1_GHZ_RF_P: U4.7 (BP_SUB1-_GHZ_RF_P), U8.3 (RF_P_SUB_1GHZ)
/SW_RFI: U5.6 (SW_RFI), U6.3 (RF2)
/SW_RFO: U5.8 (SW_RFO), U6.1 (RF1)
/TXD: U3.2 (GPIO0), U8.18 (DIO_12)
/UBP_2_4_GHZ: C7.1, U4.1 (UBP_2_4_GHZ)
/UBP_SUB-1_GHZ: C8.1, C23.1
/VDDR: C15.1, C16.1, C17.1, L2.2, U8.45 (VDDR), U8.48 (VDDR_RF)
/VDDS: C10.1, C11.1, C12.1, C13.1, C14.1, L1.1, R6.2, U8.13 (VDDS2), U8.22 (VDDS3), U8.34 (VDDS_DCDC), U8.44 (VDDS)
/X48M_N: C19.1, U8.46 (X48M_N), Y1.3
/X48M_P: C18.1, U8.47 (X48M_P), Y1.1
/XTA: U7.3 (XTA), Y3.3
/XTB: U7.4 (XTB), Y3.1
/cJTAG_TCK: J3.4, U3.14 (GPIO11), U8.25 (JTAG_TCKC)
/cJTAG_TMSC: J3.2, U3.15 (GPIO12), U8.24 (JTAG_TMSC)
GND: BOOT1.1, C1.1, C2.1, C3.2, C4.2, C5.2, C10.2, C11.2, C12.2, C13.2, C14.2, C15.2, C16.2, C17.2, C18.2, C19.2, C21.2, C22.2, C24.2, C25.2, C26.2, C27.1, C28.2, C29.2, C30.2, C31.2, C32.2, C33.2, C34.2, C35.2, C36.2, C37.2, C38.2, C39.2, C40.2, C41.2, C42.2, C43.2, C44.2, C45.2, C46.2, J1.2 (Ext), J3.5, P1.A1 (GND), P1.A12 (GND), P1.B1 (GND), P1.B12 (GND), P1.S1 (SHIELD), R1.1, R2.1, R3.1, R4.1, R5.1, R9.1, RESET1.2, RESET_CC1.1, SW1.2, U1.2 (GND), U3.19 (TESTEN), U3.57 (GND), U4.2 (GND), U4.3 (GND), U4.10 (GND), U5.2 (GND), U5.5 (GND), U5.7 (GND), U5.9 (GND), U5.10 (GND), U6.2 (GND), U7.2 (GND), U7.5 (GND), U7.8 (GND), U7.20 (GND), U8.49 (EGP), U8.49_1 (EGP), U8.49_2 (EGP), U8.49_3 (EGP), U8.49_4 (EGP), U8.49_5 (EGP), U8.49_6 (EGP), U8.49_7 (EGP), U8.49_8 (EGP), U8.49_9 (EGP), U8.49_10 (EGP), U8.49_11 (EGP), U8.49_12 (EGP), U8.49_13 (EGP), U8.49_14 (EGP), U8.49_15 (EGP), U8.49_16 (EGP), U8.49_17 (EGP), U8.49_18 (EGP), U8.49_19 (EGP), U8.49_20 (EGP), U8.49_21 (EGP), U9.4 (GND), Y1.2, Y1.4, Y3.2, Y3.4, Y4.2, Y4.4
unnamed: C20.2, C26.1, L3.2
unnamed: C28.1, R12.1, Y4.3
unnamed: D1.1 (K), R3.2
unnamed: D2.1 (K), R4.2
unnamed: D3.1 (K), R5.2
unnamed: D4.1 (K), R9.2
unnamed: F1.1, P1.A4 (VBUS), P1.A9 (VBUS), P1.B4 (VBUS), P1.B9 (VBUS)
unnamed: JP1.2 (C), R8.2
unnamed: P1.A5 (CC), R1.2
unnamed: P1.B5 (VCONN), R2.2
unnamed: C9.1, U2.2 (ANT)
unnamed: C6.2, U2.4 (RF1)
unnamed: C7.2, U2.8 (RF2)
unnamed: C8.2, U2.5 (RF3)
unnamed: R11.2, U3.46 (USB_DM)
unnamed: R10.2, U3.47 (USB_DP)
unnamed: C4.1, U3.20 (XIN), Y4.1
unnamed: R12.2, U3.21 (XOUT)
unnamed: C23.2, U4.4 (UBP_SUB-1_GHZ)
unnamed: C20.1, U6.5 (RFC)
unnamed: C31.1, R7.1, U6.6 (V1)
unnamed: C35.1, R8.1, U6.4 (V2)
unnamed: L5.1, U7.9 (DCC_SW)
unnamed: C33.1, L5.2, U7.7 (VREG)
unnamed: C21.1, C22.1, L4.1, U7.24 (VR_PA)
unnamed: C37.1, U8.23 (DCOUPL)
unnamed: C34.1, U8.8 (X32K_Q1), Y2.1
unnamed: C36.1, U8.9 (X32K_Q2), Y2.2
VCC: C1.2, F1.2, U1.1 (VIN), U1.3 (EN)

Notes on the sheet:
RF1 to ANT
cJTAG - Matching CC1350
Rx to ANT
Pin 48
Pin 33
2.4Ghz
CRF2
REGULATOR AND BATTERY
SWD FOR RP2040
ANTENNA MATCHING LORA
RF1
SWITCH LORA
ANTENNA MATCHING 2.4 AND 1 GHZ
Pin 34
Pin 45
CRF1
FILTERING VOLTAGE
Condition
Pin 44
Technology
FLASH
Pin 22
Tx to ANT
MAIN RF SWITCH
BUTTONS
Pin 13
CC1352
LoRa
CRF3
Sub-Gig
MICROCONTROLLER
USB
SX1262 AND RF SWITCH
LEDS
RF2

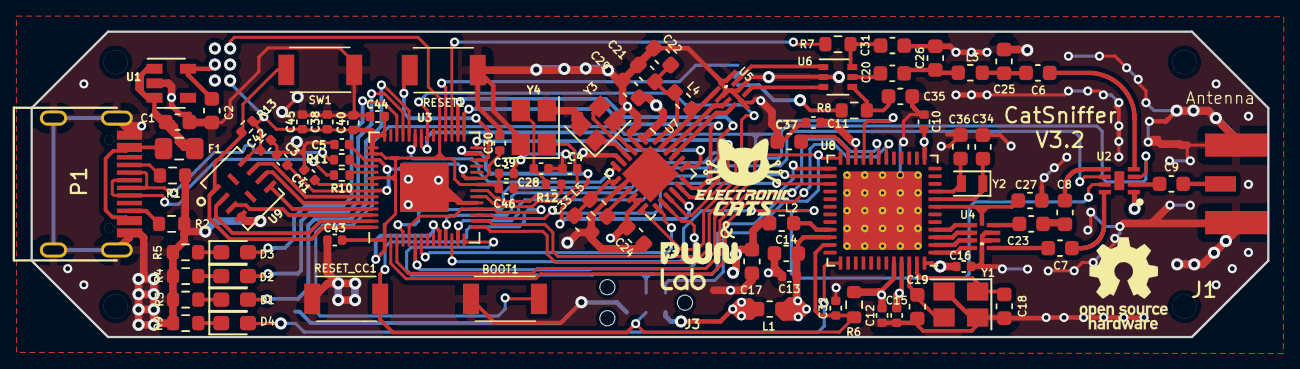
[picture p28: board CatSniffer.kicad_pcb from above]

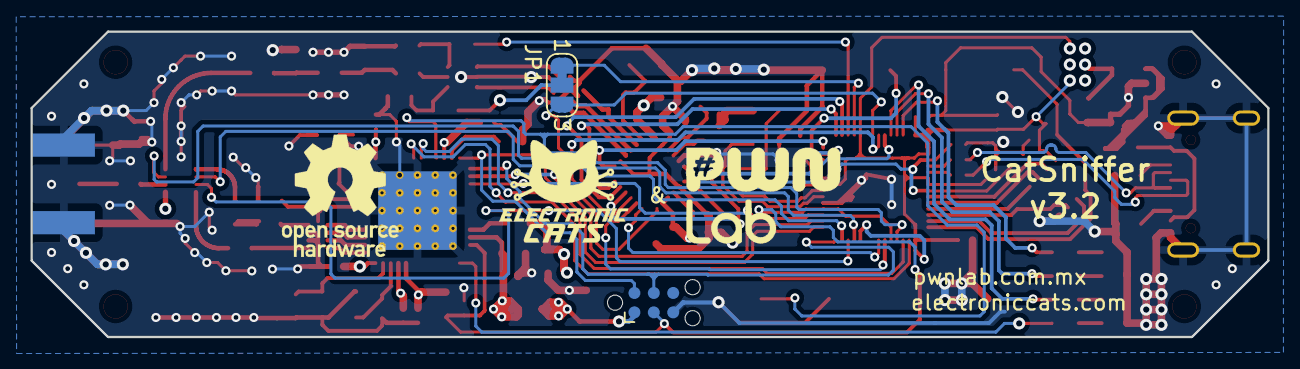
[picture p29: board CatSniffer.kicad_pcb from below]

Board: 4 copper layers, 81.0 x 20.0 mm, 90 parts (2 on the bottom side), 88 nets.

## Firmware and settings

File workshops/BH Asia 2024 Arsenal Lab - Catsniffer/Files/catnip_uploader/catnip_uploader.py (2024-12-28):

# Catnip Uploader is a Python script that allows you to upload firmware to CatSniffer boards V3.
# This file is part of the CatSniffer project, http://electroniccats.com/
# GNU GENERAL PUBLIC LICENSE
# Version 1 2024
# Kevin Leon <@kevlem97>

# Copyright (C) 2007 Free Software Foundation, Inc. https://fsf.org/
# Everyone is permitted to copy and distribute verbatim copies
# of this license document, but changing it is not allowed.

import typer
import serial
import platform
import requests
import io
import os
import time
import json
import sys

if platform.system() == "Windows":
    DEFAULT_COMPORT = "COM1"
elif platform.system() == "Darwin":
    DEFAULT_COMPORT = "/dev/tty.usbmodem0001"
else:
    DEFAULT_COMPORT = "/dev/ttyACM0"

GITHUB_RELEASE_URL               = "https://api.github.com/repos/ElectronicCats/CatSniffer-Firmware/releases/latest"
RELEASE_JSON_FILENAME = "board_release.json"
TMP_FILE                 = "firmware.hex"
COMMAND_ENTER_BOOTLOADER = "ñÿ<boot>ÿñ"
COMMAND_EXIT_BOOTLOADER  = "ñÿ<exit>ÿñ"

def LOG_INFO(message):
    """Function to log information."""
    print(f"[INFO] {message}")

def LOG_ERROR(message):
    """Function to log error."""
    print(f"\x1b[31;1m[ERROR] {message}\x1b[0m")

def LOG_WARNING(message):
    """Function to log warning."""
    print(f"\x1b[33;1m[WARNING] {message}\x1b[0m")

def LOG_SUCCESS(message):
    """Function to log success."""
    print(f"\x1b[32;1m[SUCCESS] {message}\x1b[0m")

def validate_python_call():
    command = "python --version"
    output = os.popen(command).read()
    if output.find("Python 3.") == -1:
        command = "python3 --version"
        output = os.popen(command).read()
        if output.find("Python 3.") == -1:
            LOG_ERROR("Python 3 is required to run this program.")
            sys.exit(1)
        
        return "python3"
    
    return "python"

def validate_firmware_selected(firmware_selected: int):
    get_release = release_handler.get_local_releases_dict()
    #get_release = release_handler.get_release()
    LOG_INFO(f"Validating selected firmware: {firmware_selected} - {get_release[firmware_selected]}")
    if firmware_selected not in get_release:
        LOG_ERROR(f"Selected firmware invalid: {firmware_selected}")
        sys.exit(1)
    
    LOG_SUCCESS(f"Valid firmware selected: {firmware_selected}")
class Release:
    def __init__(self):
        self.release_data = None
        self.temp_filename = "releases.json"
        self.tag_version = None 
        self.release_json = self.__fetch_release()
    
    def __fetch_assets(self):
        """Fetch the assets from the release."""
        try:
            request_release = requests.get(f"{GITHUB_RELEASE_URL}")
            request_release.raise_for_status()

            if request_release.status_code != 200:
                LOG_ERROR(f"Error fetching assets: {request_release.status_code}")
                sys.exit(1)

            req_release_data = request_release.json()
            LOG_INFO(f"Fetching assets from {GITHUB_RELEASE_URL}")
            LOG_INFO(f"Release: {req_release_data['tag_name']}")

            self.tag_version = req_release_data['tag_name']

            return req_release_data["assets"]
        except requests.exceptions.ConnectionError as e:
            has_local_release = self.find_folder_releases()
            if has_local_release is not None:
                return None
            LOG_ERROR("Error. You need internet connection for the first use to download the firmware")
            sys.exit(1)
        except Exception as e:
            LOG_ERROR(f"Error fetching assets: {e}")
            sys.exit(1)


    def __fetch_release(self):
        """Fetch the release data from the repo."""
        try:
            firmware_releases = []
            repo_assets = self.__fetch_assets()
            if repo_assets is None:
                return self.get_local_releases_dict()
            # Check if the lasted release is already downloaded
            has_local_release = self.find_folder_releases()
            if has_local_release is not None:
                # The local release is found
                LOG_INFO(f"Found local release: {has_local_release}")
                has_lasted_release = self.has_lasted_release(self.tag_version)
                if has_lasted_release:
                    LOG_SUCCESS(f"Local release is up to date: {self.tag_version}")
                    firmware_releases = self.get_local_releases_dict()
                    return firmware_releases
                else:
                    LOG_WARNING(f"Updating local release: {has_local_release} to {self.tag_version}")

            LOG_INFO("Fetching release data")

            self.create_release_folder(self.tag_version)
            

            for asset in repo_assets:
                if asset["name"] == RELEASE_JSON_FILENAME:
                    req_release_data = asset["browser_download_url"]
                    request_release = requests.get(req_release_data)
                    content = request_release.content
                    content_bytes = io.BytesIO(content)
                    
                    self.write_json_file(self.temp_filename, content_bytes.read().decode())
                    self.release_data = self.read_json_file(self.temp_filename)
                else:
                    # To avoid the uf3 files until we have a way to upload them
                    if asset["name"].endswith(".hex"):
                        with open(os.path.join(f"releases_{self.tag_version}", asset["name"]), "wb") as f:
                            request_release = requests.get(asset["browser_download_url"])
                            content_bytes = io.BytesIO(request_release.content)
                            f.write(content_bytes.read())
                            firmware_releases.append(asset["name"])
            return self.__create_dict_release(firmware_releases)
        except Exception as e:
            LOG_ERROR(f"Error with the repo assets. Please check the current version of the script and the release: {e}")
            sys.exit(1)

    def __create_dict_release(self, release_data: dict = None):
        """Create a dictionary with the release data."""
        release_dict = {}
        for index, release in enumerate(release_data):
            release_dict[index] = release
        return release_dict

    def get_release(self):
        """Return the release data. If it's not available, return the local release data."""
        if self.release_json is None:
            self.release_json = self.get_local_releases_dict()
        return self.release_json
    
    def read_json_file(self, filename: str):
        with open(filename, "r") as f:
            return json.load(f)
    
    def write_json_file(self, filename: str, data) -> None:
        with open(filename, "w") as f:
            f.write(json.dumps(data))
    
    def remove_local_files_releases(self, release_folder: str) -> None:
        """Clean up the local releases folder."""
        list_files = os.listdir(release_folder)
        for file in list_files:
            os.remove(os.path.join(release_folder, file)) 

    def has_lasted_release(self, lasted_release) -> bool:
        """Check if the lasted release is already downloaded."""
        dir_files = os.listdir(os.getcwd())
        for dir_name in dir_files:
            if dir_name.startswith("releases_"):
                if dir_name.replace("releases_", "") == lasted_release:
                    return True
        return False

    def get_local_releases_dict(self) -> dict:
        """Get the local releases."""
        release_folder = self.find_folder_releases()
        if release_folder is not None:
            list_files = os.listdir(release_folder)
            return self.__create_dict_release(list_files)
        return {}

    def find_folder_releases(self) -> str:
        """Find the releases folder."""
        dir_files = os.listdir(os.getcwd())
        for dir_name in dir_files:
            if dir_name.startswith("releases_"):
                return dir_name
        return None

    def create_release_folder(self, tag_version):
        """Create the release folder."""
        if tag_version is None:
            return
        exist_prev_release = self.find_folder_releases()
        if exist_prev_release is None:
            if not os.path.exists(f"releases_{tag_version}"):
                os.mkdir(f"releases_{tag_version}")
        else:
            LOG_WARNING(f"Previous release found: {exist_prev_release} updating to {tag_version}")
            self.remove_local_files_releases(exist_prev_release)
            os.rename(exist_prev_release, f"releases_{tag_version}")
            
    def get_firmware_releases(self, firmware_selected: int):
        """Get the firmware releases."""
        releases_firmware = self.get_local_releases_dict()
        print(releases_firmware[firmware_selected])
        if releases_firmware is None:
            LOG_ERROR(f"Error with the releases folder")
            return None
        
        return os.path.join(self.find_folder_releases(), releases_firmware[firmware_selected])


class BoardUart:
    def __init__(self, serial_port: str = DEFAULT_COMPORT):
        self.serial_worker          = serial.Serial()
        self.serial_worker.port     = serial_port
        self.serial_worker.baudrate = 921600
        self.firmware_selected      = 0
        self.command_to_send        = f"cc2538.py -e -w -v -p {self.serial_worker.port}"
        self.python_command         = validate_python_call()
    
    def validate_connection(self):
        try:
            self.serial_worker.open()
            self.serial_worker.close()
            return True
        except serial.SerialException:
            return False
    
    def set_firmware_selected(self, firmware_selected: str):
        self.firmware_selected = firmware_selected

    def send_connect_boot(self):
        self.serial_worker.open()
        self.serial_worker.write(COMMAND_ENTER_BOOTLOADER.encode())
        self.serial_worker.close()
    
    def send_disconnect_boot(self):
        self.serial_worker.open()
        self.serial_worker.write(COMMAND_EXIT_BOOTLOADER.encode())
        self.serial_worker.close()
    
    def send_firmware(self):
        LOG_INFO(f"Getting {self.firmware_selected} - {release_handler.get_release()[self.firmware_selected]}")
        firmware_bytes = release_handler.get_firmware_releases(self.firmware_selected)
        if firmware_bytes is None:
            LOG_ERROR(f"Error reading firmware: {self.firmware_selected}")
            sys.exit(1)
        
        LOG_INFO(f"Uploading {release_handler.get_release()[self.firmware_selected]} to {self.serial_worker.port}")
        
        self.send_connect_boot()
        time.sleep(1)
        #TODO: Add a check to see if the command was successful
        os.system(f"{self.python_command} {self.command_to_send} {firmware_bytes}")
        time.sleep(1)
        self.send_disconnect_boot()
        LOG_SUCCESS(f"Done uploading {self.firmware_selected} to {self.serial_worker.port}")
    
    def create_tmp_file(self, content_bytes):
        with open(TMP_FILE, "w") as f:
            f.write(content_bytes)

    def remove_tmp_file(self):
        os.remove(TMP_FILE)
    

release_handler = Release()

app = typer.Typer(
    name = "Catnip Uploader",
    help = "Upload firmware to CatSniffer boards V3.",
    add_completion = False,
    no_args_is_help = True
)

@app.command("releases")
def list_releases():
    """List all available releases"""
    LOG_SUCCESS("Available releases:")
    get_release = release_handler.get_release()
    for release in get_release:
        typer.echo(f"{release}: {get_release[release]}")

@app.command("load")
def load_firmware(firmware_selected: int = typer.Argument(
        default=0,
        help=f"Set the firmware to load.",
    ),
    comport: str = typer.Argument(
        default=DEFAULT_COMPORT,
        help="Serial port to use for uploading.",
    ),
):
    """Load firmware to the board"""
    validate_firmware_selected(firmware_selected)
    serial_connection = BoardUart(comport)

    serial_connection.set_firmware_selected(firmware_selected)

    if not serial_connection.validate_connection():
        LOG_ERROR(f"Invalid serial port: {comport}")
        sys.exit(1)
    
    serial_connection.send_firmware()

if __name__ == "__main__":
    app()
